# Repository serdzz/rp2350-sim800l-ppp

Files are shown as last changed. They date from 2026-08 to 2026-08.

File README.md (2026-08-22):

# RP2350-Plus + SIM800L → PPP → embassy-net

Embassy-приложение для Waveshare RP2350-Plus, которое поднимает интернет через
GSM-модуль SIM800L: настройка модема на `atat`, IP-канал на `embassy-net-ppp`,
сокеты на `embassy-net`.

```
┌──────────── командный режим ────────────┐   ┌──────── data-режим ────────┐
 BufferedUart ──► atat::Ingress ──► ResponseSlot / UrcChannel
      ▲                                          BufferedUart ──► embassy-net-ppp
      └── atat::Client ── AT+CGDCONT / ATD*99#                          │
                                                          embassy-net (TCP/UDP/DNS)
```

Один и тот же UART обслуживает обе фазы, но **никогда одновременно**. Пока идёт
AT-настройка, задача ingress живёт внутри `select` и снимается автоматически, как
только модем ответил `CONNECT`. После этого UART целиком уходит в
`embassy_net_ppp::Runner::run`. Когда PPP-сессия разваливается, приложение шлёт
`+++` / `ATH`, возвращается в командный режим и повторяет цикл.

## Документация

* [ARCHITECTURE.md](ARCHITECTURE.md) — как собрана прошивка: задачи, потоки
  данных, ключевые решения и расход ресурсов.
* [hardware/nri-g13-shifter/](hardware/nri-g13-shifter/) — схема переходника
  монетоприёмника на BSS138 (KiCad).
* [docs/cmux.md](docs/cmux.md) — мультиплексор 27.010: формат кадров, ловушки
  спецификации, раздача каналов и находки на живом железе.

## Файлы

| Файл | Что внутри |
|---|---|
| `src/main.rs` | Инициализация периферии, стек, главный цикл «AT → PPP → восстановление» |
| `src/config.rs` | **APN, логин/пароль, строка дозвона, таймауты** — правьте здесь |
| `src/modem.rs` | AT-команды, ответы и URC для `atat` |
| `src/sim800l.rs` | Питание модуля и последовательность инициализации до `CONNECT` |
| `src/cmux.rs` | Протокол 27.010: кадры, сессия, управляющий канал — см. [docs/cmux.md](docs/cmux.md) |
| `src/cmux_transport.rs` | Раздача каналов CMUX поверх одного UART |
| `src/mqtt.rs` | Телеметрия и приём SMS в MQTT, подписка на команды |
| `src/led.rs` | Режимы зелёного светодиода на GP25 |
| `src/display.rs` | Экран SSD1306 по I2C: часы, заряд, шкала сигнала, состояние связи |
| `src/fuel.rs` | Топливомер MAX17048 на той же шине I2C |
| `src/coin.rs` | Кредит, коды монет, разбор команд (без зависимостей, тесты на хосте) |
| `src/coin_io.rs` | Линии монетоприёмника NRI G-13: снятие кода монеты и блокировка |
| `src/clock.rs` | Время от сети и шкала сигнала (без зависимостей, тесты на хосте) |
| `src/health.rs` | Счётчики обрывов связи (без зависимостей, тесты на хосте) |
| `src/app.rs` | Демо-нагрузка поверх поднятого IP: DNS + HTTP GET |
| `src/battery.rs` | Замер VSYS/VBAT, определение источника питания |
| `src/lipo.rs` | Кривая заряда Li-Po (без зависимостей, тестируется на хосте) |
| `src/fmt.rs` | Фасад логирования: `info!`/`warn!`/`unwrap!` → defmt или log |
| `src/usb_logger.rs` | USB CDC-ACM логгер (только в сборке `log-usb`) |
| `src/io_compat.rs` | Мост `embedded-io-async` 0.7 ↔ 0.6 (см. «Версии крейтов») |
| `at-tests/` | Хостовые тесты формата AT-команд и дайджестера |

## Схема подключения

| SIM800L | RP2350-Plus | Примечание |
|---|---|---|
| `TXD` | `GP1` (UART0 RX) | |
| `RXD` | `GP0` (UART0 TX) | **нужен делитель 3.3 В → 2.8 В** |
| `PWRKEY` | `GP2` | опционально, если модуль не стартует сам |
| — | `GP16` / `GP17` | SDA / SCL: экран SSD1306 и топливомер MAX17048 (I2C0) |
| — | `GP3`…`GP8` | линии монетоприёмника, см. ниже |
| `GND` | `GND` | общая земля обязательна |
| `VCC` | **отдельный источник 3.4–4.4 В** | 2 А импульсами |

Два момента, на которых спотыкается большинство сборок:

1. **Питание.** SIM800L в момент передачи потребляет до 2 А. От пина `3V3` платы
   он не заработает — нужен отдельный источник (Li-Ion, LDO на 4 В) и
   конденсатор 1000 мкФ рядом с модулем. Симптом нехватки тока — URC
   `NORMAL POWER DOWN` в логе.
2. **Уровни.** Вход `RXD` модуля рассчитан на 2.8 В. Подавать на него 3.3 В
   напрямую — за пределами спецификации; поставьте делитель или преобразователь
   уровней. Выход `TXD` (2.8 В) RP2350 читает как логическую единицу без
   доработок.

Пины UART меняются в `src/main.rs` (`p.PIN_0` / `p.PIN_1`), но оставайтесь в
пределах одного `UART0` — иначе поправьте и `bind_interrupts!`.

## Топливомер MAX17048

SparkFun Qwiic Fuel Gauge вешается на ту же шину I2C, что и экран: `GP16` (SDA)
и `GP17` (SCL), адрес `0x36`. Аккумулятор подключается к самому топливомеру, а
не к плате — он меряет напряжение прямо на банке.

Заряд выводится на экран рядом с часами. Если топливомера нет, там стоит
прочерк: пустое место читалось бы как «показа заряда не предусмотрено».

### Зачем он, если есть замер VSYS

Затем, что `battery.rs` меряет не банку, а VSYS, и **при воткнутом USB о
батарее не говорит ничего** — VBUS через диод задаёт VSYS независимо от её
состояния. В логе это видно как «батарея не измеряется» в каждой строке.

У MAX17048 такого ограничения нет. И считает он заряд не по напряжению, а по
своей модели разряда: под нагрузкой напряжение проседает, и пересчёт
«вольты → проценты» врёт тем сильнее, чем больше ток. У модема этот ток
доходит до двух ампер.

### Про общую шину

Экран работает с шиной асинхронно, а крейт `max170xx` блокирующий. Свести их
удалось потому, что `embassy_rp::I2c` реализует оба трейта сразу: экран ходит
через асинхронную обёртку `I2cDevice`, а топливомер берёт мьютекс и обращается
к шине напрямую. Транзакция там короткая, пара байт, так что блокировка внутри
асинхронной задачи безобидна.

## Монетоприёмник NRI G-13

Вариант с шестью параллельными линиями (не последовательный интерфейс).

| Контакт разъёма | Сигнал | RP2350-Plus |
|---|---|---|
| 1 | `GND` | `GND` |
| 2 | `UB` +12 В | отдельный источник 10–16 В, ~20 мА |
| 7 | output line 1 | `GP3` |
| 8 | output line 2 | `GP4` |
| 9 | output line 3 | `GP5` |
| 10 | output line 4 | `GP6` |
| 3 | output line 5 | `GP7` |
| 4 | output line 6 | `GP8` |
| 6 | total blocking | `GP9` через ключ, см. ниже |

Нумерация контактов и линий не совпадает — сверяйтесь с таблицей, а не со
здравым смыслом.

Каждая линия **двунаправленная**: приёмник выдаёт по ней импульс 100 мс при
опознанной монете, и она же, удерживаемая в нуле, блокирует свой канал.
Поэтому в прошивке это `Flex`, а не обычный вход: открытый канал — вход с
подтяжкой, закрытый — выход, притянутый к земле. Высокий уровень на линию не
выдаётся никогда — с той стороны открытый коллектор.

### Согласование уровней: BSS138 на каждую линию

Линии приёмника живут в 12-вольтовом мире, плата — в 3,3-вольтовом, и по
каждой линии нужно и читать, и писать. Проверенное решение — **двунаправленный
преобразователь на BSS138**, по одному на линию:

```text
        +3.3 В (затвор)
             │
   GP3 ──────┤ BSS138 ├────── output line 1
   (вход с      (сток к приёмнику,
    подтяжкой)   исток к плате)
```

Внешние резисторы не нужны: со стороны платы работает встроенная подтяжка
RP2350 (её включает `Flex::set_pull(Pull::Up)`), со стороны приёмника — его
собственная. Так собран рабочий автомат на MSP430
(`bahilizator_svn/hardware/main_baord/coin.sch`, `Q10…Q15`), и там же прошивка
включает внутренние подтяжки контроллера.

Для справки, требования из схемы подключения (`G-13.6000-1 d`, стр. 22):

| | напряжение |
|---|---|
| блокировка канала | `≤ 1 В` |
| приём канала | `≥ 3,5 В` |
| допустимое на линии | до 35 В, до 150 мА |

Заводить линии на выводы напрямую **нельзя**: 3,3 В ниже порога приёма, и это
ещё до вопроса о том, что на линии может оказаться.

### Полная блокировка (контакт 6)

Закрывает приём целиком, независимо от поканальной маски. Активен **высоким**:
блокировка `≥ 3,5 В`, приём `≤ 1 В`, выдерживает до 35 В.

Схема та же, что у линий, плюс подтяжка стока к `+5 В` — так это сделано в
рабочем автомате (`Q5` и `R45` 10 кОм на той же схеме):

```text
                        +3.3 В        +5 В
                           │            │
                           │           10к
                           │            │
  GP9 ──10к── +3.3 В   ────┤ BSS138 ├───┴──── контакт 6 (total blocking)
```

Каскад **не инвертирует**: `GP9` высокий → полевик закрыт → 10к тянет линию к
5 В → блокировка. Поэтому в `src/config.rs`:

```rust
pub const COIN_TOTAL_BLOCK_INVERTED: bool = false;
```

Резистор 10 кОм от `GP9` к `+3.3 В` — не из схемы-образца, а добавка: без него
вывод в сбросе не управляется, линия уходит к нулю, и **мёртвый автомат
принимает монеты, не давая кредита**. С подтяжкой неуправляемый вывод означает
«заблокировано».

Если собрали инвертирующий каскад (например, NPN с подтяжкой к +12 В),
поставьте `COIN_TOTAL_BLOCK_INVERTED = true`.

### Монета опознаётся кодом на линиях

Прошивка снимает состояние всех шести линий разом и ищет получившийся код в
таблице. Это покрывает оба способа, которыми приёмник умеет сообщать монету:

* **одна монета на линию** — код однобитный (`0b010000` = линия 5);
* **двоичный код** — код многобитный (`0b000101` = пины 1 и 3 вместе).

Второе документация допускает прямо: «possible to transmit coin signals in a
binary code or assign more than one line to a type of coin».

Считать линии по отдельности нельзя: при двоичном коде одно евро зажигает два
пина, и шесть независимых счётчиков насчитали бы две монеты.

### Столбец на шильдике читается двояко — решает монета

Значения 1…6 в столбце — это либо номер линии, либо код. Глазами это не
различить, поэтому в `src/config.rs` перечислены **оба** варианта:

```rust
pub const COINS: &[coin::Coin] = &[
    coin::Coin { mask: 0b010000, value: 100, name: "EUR 1 (линия 5)" },
    coin::Coin { mask: 0b000101, value: 100, name: "EUR 1 (код 5)" },
    coin::Coin { mask: 0b100000, value: 100, name: "жетон (линия 6)" },
    coin::Coin { mask: 0b000110, value: 100, name: "жетон (код 6)" },
];
```

Столкнуться они не могут: при однобитной раскладке `0b000101` не появится
никогда (две линии разом не зажигаются), при двоичной не появится `0b010000`
(кода 16 на шильдике нет). Бросьте монету — лог скажет, какой вариант ваш:

```
COIN: EUR 1 (линия 5) (код 0b010000), номинал 100, кредит 100
```

Увидели — лишнюю строку из таблицы удалите. Неизвестный код печатается готовым
к вписыванию.

Для справки, что на шильдике экземпляра `06V01/5-14000084-008` (11/06):

| Столбец | Монета | Каналы |
|---|---|---|
| 1 | LVL 1,- | 01, 06 |
| 2 | RUR 5,- | 02, 07 |
| 3 | UAH 0,50 | 03, 08 |
| 4 | UAH 1,- | 04, 09 |
| 5 | **EUR 1,-** | 05, 10 |
| 6 | жетон | 12…16 |

Жетоны различить нельзя — все пять каналов дают один код.

### Ненужные монеты глушите переключателями, а не линиями

Латы, рубли и гривны прошивка не засчитает, но приёмник их всё равно
**проглотит** — они провалятся в кассу, а клиент останется без товара и без
денег. Закрывать их надо на самом приёмнике, по каналам:

* `S1.1…8` — каналы 1–8, `S2.1…8` — каналы 9–16;
* монета занимает **два канала** (обычная полоса приёма и узкая), выключать
  надо оба: лат — это `S1.1` и `S1.6`.

Команда `coin/block` глушит линии и остаётся полезной при однобитной раскладке.
При двоичном коде она почти бесполезна: пин 1 участвует и в лате, и в гривне, и
в евро, так что закрытие линии калечит чужие коды. Поэтому
`COIN_BLOCK_DEFAULT` равен нулю.

### Можно ли принимать евро кроме одного

Только 1 € запрограммирован заводом. Два блока настроек (`B-0` / `B-1`,
переключатель `S1.10`) у этого экземпляра содержат одинаковые наборы, так что
переключение ничего не даст.

Зато доступно обучение: `S2.9` = TEACH Mode, учить можно каналы 10 и 11, из
которых **11 свободен**. Порядок: `S2.9` в TEACH, `S2.3` (канал 11) включить,
бросить монету 10 раз до щелчка заслонки, оба переключателя выключить — второй
щелчок означает, что записалось. Два щелчка вместо одного — не записалось,
обычно из-за перекрытия с уже известной монетой; тогда повторить с `S2.10` в
положении `Teachband wide`.

Полный набор евро (10/20/50 центов, 2 €) требует программатора NRI с
программой KUNEMP.

### Переключатели на корпусе

| Группа | Позиции | Функция |
|---|---|---|
| S1 | 1…8 | заглушить каналы 1–8 |
| S1 | 9 | CASINO / NORMAL |
| S1 | 10 | Block 1 / Block 0 |
| S2 | 1…8 | заглушить каналы 9–16 |
| S2 | 9 | TEACH / NORMAL |
| S2 | 10 | Teachband wide / normal |

## Топики MQTT

| Топик | Направление | Тело |
|---|---|---|
| `rp2350-sim800l/csq` | публикуем, retain | `<rssi>` из `+CSQ`, раз в 60 с |
| `rp2350-sim800l/sms` | публикуем, retain | текст принятого SMS |
| `rp2350-sim800l/coin` | публикуем | `{"coin":"EUR 1","code":5,"value":100,"credit":100}` |
| `rp2350-sim800l/led` | подписаны | `ON`, `OFF`, `BLINK`, `TOGGLE` |
| `rp2350-sim800l/coin/block` | подписаны | `none`, `all`, `1,3` — какие линии заблокировать |
| `rp2350-sim800l/sms/send/<номер>` | подписаны | текст SMS в теле, номер в топике |
| `rp2350-sim800l/coin/total` | подписаны | `block` / `accept` — закрыть приём целиком |

Событие монеты идёт без `retain`: оно имеет смысл в момент наступления, а не
как последнее известное состояние. Команда блокировки, наоборот, задаёт
состояние целиком — присланная маска заменяет предыдущую, а не дополняет её.

Поканальная и полная блокировки независимы: закрытый автомат не отменяет того,
какие монеты в нём не принимаются, когда он открыт. Тело `block`/`accept`, а не
`on`/`off`, потому что «ON» одинаково правдоподобно читается и как «блокировка
включена», и как «приём включён». Пока приём закрыт, на экране рядом с кредитом
горит `ЗАКРЫТО` — иначе закрытый приёмник выглядит как сломанный.

### Отправка SMS

Номер — последний сегмент топика, текст — тело сообщения:

```bash
mosquitto_pub -h broker.hivemq.com \
  -t rp2350-sim800l/sms/send/37120000000 -m 'Coin jam on line 3'
```

**Номер только цифрами, без плюса.** В имени топика MQTT плюс запрещён — это
подстановочный знак, — и брокер такую публикацию отвергнет. Прошивка
подставляет его сама.

**Текст только ASCII, до 160 символов.** Кириллица требует `AT+CSCS="UCS2"` и
перекодировки всего сообщения вместе с номером; отправить её как есть — значит
получить абракадабру, поэтому прошивка честно отказывается и пишет причину в
лог.

Отправка идёт не из MQTT-задачи, а из той, что держит AT-канал: она занимает
секунды и требует модема, а MQTT-клиент за это время потерял бы соединение по
keepalive. Между командой и отправкой сообщение лежит в очереди на четыре
штуки.

```bash
# закрыть приём целиком
mosquitto_pub -h broker.hivemq.com -t rp2350-sim800l/coin/total -m 'block'

# заблокировать первую и третью линии
mosquitto_pub -h broker.hivemq.com -t rp2350-sim800l/coin/block -m '1,3'
# снять блокировку
mosquitto_pub -h broker.hivemq.com -t rp2350-sim800l/coin/block -m 'none'
```

## Настройка под оператора

Всё в `src/config.rs`:

```rust
pub const APN: &str = "internet";          // APN оператора
pub const PPP_USERNAME: &[u8] = b"";       // PAP-логин, обычно пустой
pub const PPP_PASSWORD: &[u8] = b"";
pub const DIAL_STRING: &str = "*99***1#";  // некоторые прошивки хотят "*99#"
```

## Логи: два бэкенда

Выбираются feature-флагом, включён должен быть ровно один. Макросы
`info!`/`warn!`/`error!`/`debug!`/`unwrap!` объявлены в `src/fmt.rs` и
разворачиваются либо в `defmt`, либо в `log` — код приложения от выбора не
зависит.

| | `log-rtt` (по умолчанию) | `log-usb` |
|---|---|---|
| Транспорт | RTT через отладчик | USB CDC-ACM (виртуальный COM-порт) |
| Нужен отладчик | да | **нет** |
| Чем читать | `probe-rs` / `cargo run` | любой serial-терминал |
| Паники | печатаются с бэктрейсом | не видны (см. ниже) |
| Flash | ~197 КиБ | ~201 КиБ |
| RAM (bss) | ~44 КиБ | ~45 КиБ |

### `log-usb`: лог по USB, без отладчика

```bash
cargo build-usb        # алиас в .cargo/config.toml

# BOOTSEL + USB, затем:
picotool load -u -v -x -t elf target/thumbv8m.main-none-eabihf/release/rp2350-sim800l

# Плата поднимется как виртуальный COM-порт:
screen /dev/tty.usbmodem*  115200      # macOS
picocom /dev/ttyACM0 -b 115200         # Linux
```

Скорость порта роли не играет — CDC-ACM её игнорирует. Формат строки:

```
[INFO ] 4.312 SIM800L: CPIN = READY
```

Если читаете порт скриптом, а не `screen`/`picocom`, переведите tty в raw —
иначе терминальная дисциплина портит многобайтные UTF-8 символы (кириллица
в логе поедет):

```bash
stty -f /dev/cu.usbmodem* raw -echo -istrip
```

Готовый вариант со всем этим внутри:

```bash
./tools/capture-log.py 120        # 120 секунд лога
```

Он же говорит, если порт занят: терминал держит устройство монопольно, и
запущенный `screen` со стороны выглядит как намертво замолчавшая плата.

Что стоит знать про этот режим:

* **Первые строки теряются.** Хост enumerate'ит порт около секунды; всё, что
  приложение успело написать раньше, оседает в буфере на 2 КиБ и вытесняется.
  Чтобы поймать самый старт — держите терминал открытым и передёрните плату
  кнопкой RUN.
* **Паники не видны.** `panic-probe` без `print-defmt` просто выполняет `udf`,
  а отправить сообщение через USB уже некому: executor остановлен. Отлаживать
  паники нужно в RTT-сборке.
* **`atat` молчит.** У версии 0.24 нет feature `log`, поэтому её внутренние
  сообщения в этом режиме пропадают. Логи самого приложения не страдают.
* VID/PID `0xc0de:0xcafe` — тестовая пара из примеров Embassy. Для серийного
  изделия нужна своя.

Порог логирования и размер буфера — константы `LEVEL` и `LOG_BUF_SIZE` в
`src/usb_logger.rs`.

### Диагностика подключения к сети

Лог при инициализации показывает не «получилось / не получилось», а причину:

```
SIM800L: IMSI 2470xxxxxxxxxxx — домашняя сеть MCC 247 / MNC 02
SIM800L: CSQ 20 (-73 дБм) | CREG 2 — ищет сеть | CGREG 2 — ищет сеть
SIM800L: регистрации нет; сканирую сети (AT+COPS=?, до 3 мин)…
SIM800L: видимые сети: +COPS: (2,"TELE2","TELE2","24702"),(1,"LMT GSM",...)
```

Как читать `<stat>` из `+CREG?` / `+CGREG?`:

| `stat` | Значение | Куда копать |
|---|---|---|
| 0 | не ищет | радиотракт выключен |
| 1 / 5 | зарегистрирован (дома / роуминг) | норма |
| 2 | ищет сеть | питание, антенна или сети нет в эфире |
| 3 | **отказано** | сеть видна, но не пускает: SIM, тариф или роуминг |

`AT+COPS=?` (за флагом `SCAN_OPERATORS_ON_FAILURE`) показывает все сети в
эфире; первое число в скобках — `2` текущая, `1` доступна, `3` запрещена.
`IMSI` даёт домашнюю сеть карты — сравнив её со списком, видно, отказывает
свой оператор или чужой в роуминге.

**Перезагрузки модуля отслеживаются отдельно.** `RDY` во время ожидания
регистрации прерывает цикл сразу, а не через две минуты опроса уже
перезагрузившейся железки. Три перезагрузки подряд — почти наверняка провал
питания: регистрация идёт на полной мощности передатчика, и просадка сбрасывает
модуль ровно в этот момент.

## Сборка и прошивка

```bash
rustup target add thumbv8m.main-none-eabihf

# С отладчиком (Picoprobe / Raspberry Pi Debug Probe) — сразу видно defmt-лог:
cargo run --release

# Без отладчика: зажать BOOTSEL, воткнуть USB, затем
cargo build --release
picotool load -u -v -x -t elf target/thumbv8m.main-none-eabihf/release/rp2350-sim800l
```

`probe-rs` для RP2350 указан в `.cargo/config.toml` как `--chip RP235x`.

`memory.x` задан под 4 МиБ flash (минимальная комплектация RP2350-Plus). Для
16-мегабайтной версии поднимите `LENGTH` у `FLASH` до `16384K`.

Размеры выше — для сборки со включённым `USE_CMUX` и MQTT. Обе ветки подъёма
компилируются в один образ, поэтому флаг стоит около 18 КиБ; подробности в
[ARCHITECTURE.md](ARCHITECTURE.md).

## Питание: батарея, VBAT и SIM800L

Разобрано по [официальной схеме RP2350-Plus](https://files.waveshare.com/wiki/RP2350-Plus/RP2350_Plus.pdf).

```text
  VBUS ──┤>├─ D1 ──┬── VSYS ──┬── R1 200K ─┬─ Q1 SI2306 ── GP29/ADC3
  VBAT ──┤>├─ D2 ──┘          │            ├─ R7 100K ── GND
   ▲  (P3, PH1.25)            │            └─ C7 100nF ── GND
   └── ETA6096 (заряд 1 А)    └── MP28164 (buck-boost) ── 3V3
```

### Измерение напряжения

Реализовано в `src/battery.rs`, задача логирует раз в минуту.

| Сигнал | Что это |
|---|---|
| `GP29` / `ADC3` | **VSYS / 3** — делитель R1 200K / R7 100K, как на Pico |
| `GP24` | сенсор VBUS: высокий = воткнут USB |
| `GP23` | `MODE/SYNC` у MP28164: высокий = постоянная ШИМ |

`Q1` (SI2306) стоит между делителем и GP29, затвор жёстко на 3V3. Управлять им
не нужно — пока плата запитана, он открыт; когда 3V3 снят, он отвязывает GP29
от VSYS, чтобы делитель не питал ногу МК и не сажал аккумулятор.

На время замера код поднимает `GP23`: в энергосберегающем режиме преобразователя
пульсации VSYS дают разброс в десятки милливольт.

Два ограничения, которые надо принять как данность:

* **При воткнутом USB напряжение батареи не измеряется.** VSYS задаёт VBUS через
  D1 (≈4.7 В) независимо от аккумулятора, а отдельной линии замера VBAT на плате
  нет.
* На батарее `VBAT = VSYS + Vf(D2)`. Падение на диоде зависит от тока, поэтому
  `SCHOTTKY_DROP_MV` в `src/battery.rs` — прикидка (250 мВ), которую стоит
  откалибровать вольтметром прямо на аккумуляторе.

### Куда подключать питание SIM800L

| Источник | Годится | Почему |
|---|---|---|
| `3V3` (пин 36) | **нет** | 3.3 В ниже минимума 3.4 В, а MP28164 не отдаст 2 А |
| `VSYS` (пин 39) | **нет** | при USB там ≈4.7 В — выше предела 4.4 В; на батарее импульсы 2 А идут через D2 и роняют VSYS так, что плата уходит в сброс |
| **VBAT** (разъём P3 или клеммы аккумулятора) | **да** | 3.4–4.2 В ровно в окне модуля, а импульсный ток берётся с самой банки |

VBAT на 40-пиновую гребёнку **не выведен** — доступ только через батарейный
разъём PH1.25-2P. Подключаться нужно параллельно ему: Y-переходник на PH1.25
либо пайка к клеммам аккумулятора.

```text
   [Li-Po] ──┬── PH1.25 ──► RP2350-Plus (P3)
             │
             └──────────────► SIM800L VCC
                              + 1000 мкФ low-ESR у самого модуля
   GND ── общая точка (звезда от минуса аккумулятора)
```

Что учесть:

* **Электролит 1000 мкФ low-ESR прямо на пины `VCC`/`GND` модуля — обязателен.**
  Не на рейку макетки, а на сам разъём. Проверено на этом стенде: без него
  модуль уходил в перезагрузку каждые ~11 секунд (14 сбросов за 172 с), с ним —
  ни одного за 140 с. Показательно, что умирал он ровно на первой передаче:
  `CSQ` успевал вырасти с 0 до 20, и через 6 мс приходил `Break error`.
  Приём модулю даётся на десятках миллиампер, а регистрация требует передачи
  на полной мощности — поэтому симптом выглядит как «сигнал есть, регистрации
  нет».
* **Провода к модулю — короткие и толстые.** Импульсы 2 А по 577 мкс с частотой
  216 Гц: лишние 100 мОм в проводе дают просадку 0.2 В.
* **Батарея должна отдавать 2 А.** Мелкая банка на 300–500 мА·ч просядет ниже
  3.4 В на первой же передаче, и модуль выдаст `NORMAL POWER DOWN`.
* **Заряд ограничен 1 А** (R13 = 160 кОм; 82 кОм → 2 А, 66 кОм → 2.5 А). Если
  SIM800L потребляет больше, чем даёт зарядник, аккумулятор разряжается даже при
  воткнутом USB.
* **Модуль будет запитан всегда**, пока подключена батарея — даже когда плата
  выключена через `3V3_EN`. Если это важно, ставьте ключ верхнего плеча
  (P-канальный MOSFET) на линию VCC модуля или уводите модуль в power-down
  через `PWRKEY`.
* Уровни UART не меняются: `TXD` модуля 2.8 В плата читает как единицу, а на
  `GP0 → RXD` по-прежнему нужен делитель.

## Сторожевой таймер

Устройство работает без присмотра, поэтому в прошивке включён watchdog RP2350:
порог 8 секунд, кормление раз в 2 секунды из отдельной задачи.

Кормление не безусловное. Задача, кормящая по таймеру, доказывает только то,
что исполнитель крутится, — а зависнуть можно и с живым исполнителем:

| Что сломалось | Что замечает |
|---|---|
| паника, холостой цикл, зависший исполнитель | кормить некому |
| обмен с модемом встал при живых задачах | 10 минут молчания модема |

Порог молчания щедрый намеренно: в рабочем режиме модем отвечает не реже чем
раз в 30 секунд (опрос CSQ), но `AT+COPS=?` сканирует сети молча и занимает
минуты. Перезагрузка посреди сканирования была бы хуже болезни.

### PWRKEY и тёплый перезапуск

Импульс PWRKEY **переключает** питание SIM800L, а не включает его. После
перезагрузки по сторожевому таймеру модуль остался работать, и импульс бы его
выключил — поэтому на тёплом перезапуске он пропускается.

Тёплый перезапуск отличается от холодного старта по скретч-регистру watchdog:
он переживает перезагрузку чипа, но обнуляется при потере питания.

Если предположение окажется неверным и модуль всё-таки выключен, три неудачных
подъёма подряд (около полуминуты) заставят прошивку дёрнуть PWRKEY.

В логе перезагрузка видна строкой `WDT: прошлый запуск оборвала перезагрузка`.

## Тесты

```bash
./run-at-tests.sh
```

Гоняет на хосте ровно тот `src/modem.rs`, что уходит в прошивку, и проверяет
байты на проводе, разбор ответов и поведение дайджестера. Два случая, которые
эти тесты закрывают, и на которых легко обжечься:

* `ATD*99***1#` должна уйти **без кавычек** — по умолчанию `atat` заключает
  строковые аргументы в кавычки, и модем на `ATD"*99***1#"` отвечает `ERROR`.
  Отсюда `quote_escape_strings = false` у `DialPpp`.
* В перечислении `Urc` не должно быть префиксов, которые приходят ответом на
  наши же команды (`+CREG`, `+CSQ`, `+CPIN`, `+CGATT`). Дайджестер `atat`
  проверяет URC-теги **до** разбора ответа, так что такой тег увёл бы ответ в
  URC-канал, а `send()` завис бы до таймаута.

## Версии крейтов

В графе зависимостей намеренно уживаются по две версии трёх крейтов — это
следствие того, что `atat` 0.24 отстаёт от текущего Embassy:

| Крейт | `atat` | Embassy | Как разрешено |
|---|---|---|---|
| `embedded-io-async` | 0.6 | 0.7 | обёртка `Compat` в `src/io_compat.rs` |
| `heapless` | 0.8 | 0.9 | типы AT-команд используют `atat::heapless` |
| `embassy-time` | 0.4 | 0.5 | обе версии ходят в один `embassy-time-driver` 0.2, драйвер даёт `embassy-rp` — работает корректно |

Когда `atat` обновится, `src/io_compat.rs` удаляется, а `Compat(x)` в
`src/main.rs` заменяется на `x`.

## Что дальше

Полезная логика пишется в `src/app.rs` — `Stack<'static>` даёт обычные
TCP/UDP/DNS сокеты `embassy-net`. Для HTTP удобно добавить `reqwless`, для
MQTT — `rust-mqtt`; оба работают поверх `embassy-net` без изменений в этом коде.

Что стоит доделать под конкретную задачу:

* **Аппаратный flow control.** Без RTS/CTS единственная защита от переполнения —
  2 КиБ RX-буфера UART. Если модуль разведён с `RTS`/`CTS`, переключитесь на
  `BufferedUart::new_with_rtscts` и добавьте `AT+IFC=2,2` в `bring_up`.
* **Watchdog.** `embassy_rp::watchdog` на случай, если модем зависнет в
  состоянии, из которого `+++`/`ATH` не вытаскивает.
* **Экономия энергии.** `AT+CFUN=0` между сеансами и `AT+CSCLK=2` для сна модуля.

## Лицензия

Двойная, на выбор: [MIT](LICENSE-MIT) или [Apache-2.0](LICENSE-APACHE) — как
принято в экосистеме Rust и в самом Embassy.

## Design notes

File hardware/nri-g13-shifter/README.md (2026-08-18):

# Переходник NRI G-13 ↔ RP2350-Plus

Плата согласования уровней между монетоприёмником NRI G-13 (12 В) и платой
RP2350-Plus (3.3 В). Шесть линий монет и линия полной блокировки.

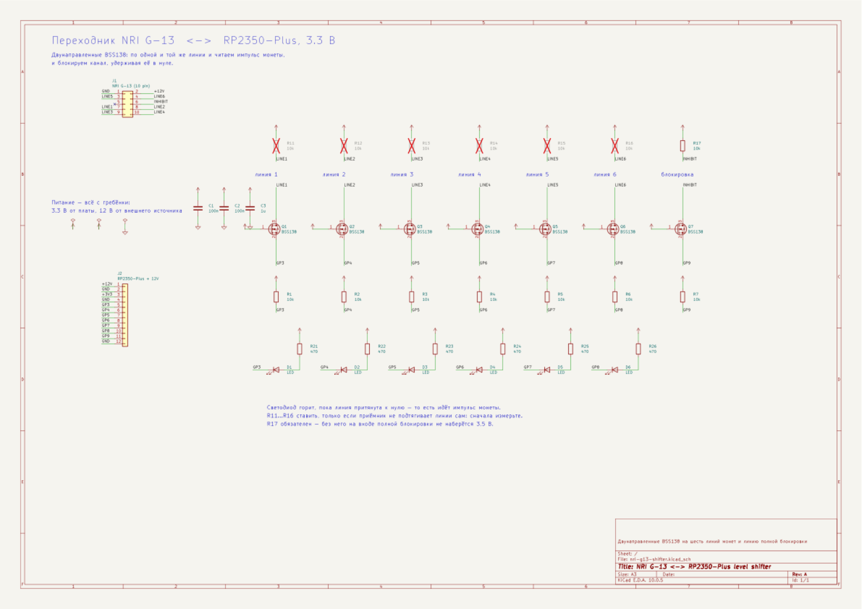
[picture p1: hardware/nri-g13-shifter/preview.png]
схема


Открывать: `nri-g13-shifter.kicad_pro`. Для просмотра без KiCad —
[nri-g13-shifter.pdf](nri-g13-shifter.pdf).

## Зачем она нужна

Линии приёмника **двунаправленные**: по одной и той же линии приходит импульс
об опознанной монете и задаётся блокировка канала — удержанием линии в нуле.
Напрямую с выводом RP2350 их соединять нельзя:

| | из даташита `G-13.6000-1 d`, стр. 22 |
|---|---|
| блокировка канала | `≤ 1 В` |
| приём канала | `≥ 3,5 В` |
| допустимо на линии | до 35 В, до 150 мА |

Порог приёма **3,5 В выше, чем выдаёт плата**. Отсюда двунаправленный
преобразователь на BSS138 — по одному на линию: затвор на 3.3 В, исток к
плате, сток к приёмнику. Ровно так сделано в предыдущем поколении устройства
(`bahilizator_svn/hardware/main_baord/coin.sch`, `Q10…Q15`).

## Разъёмы

**J1** — к приёмнику, 10 контактов. Нумерация контактов и линий **не
совпадает**, это не опечатка:

| Контакт | Сигнал | Цепь |
|---|---|---|
| 1 | GND | `GND` |
| 2 | UB +12 В | `+12V` |
| 3 | output line 5 | `LINE5` |
| 4 | output line 6 | `LINE6` |
| 5 | return | не подключён |
| 6 | total blocking | `INHIBIT` |
| 7 | output line 1 | `LINE1` |
| 8 | output line 2 | `LINE2` |
| 9 | output line 3 | `LINE3` |
| 10 | output line 4 | `LINE4` |

Контакт 5 не подключаем: он нужен только варианту Casino, где по нему идёт
сигнал датчика приёма.

**J2** — единственный разъём к остальному устройству, 12 контактов. Питание
приёмника идёт через него же: отдельный клеммник означал бы второй кабель к
устройству, которое и так стоит в тесном корпусе.

| Контакт | Цепь | Куда |
|---|---|---|
| 1 | `+12V` | внешний источник 10–16 В, ~20 мА |
| 2 | `GND` | общая земля |
| 3 | `+3V3` | с платы RP2350-Plus |
| 4 | `GND` | |
| 5…11 | `GP3`…`GP9` | линии 1…6 и блокировка |
| 12 | `GND` | |

12 В на плату RP2350-Plus, разумеется, не подаётся — этот контакт идёт мимо
неё, прямо к источнику.

## Что и зачем стоит

| Позиции | Что | Зачем |
|---|---|---|
| Q1…Q7 | BSS138 | двунаправленное согласование 3.3 В ↔ 12 В |
| R1…R7 | 10 кОм к 3.3 В | подтяжка со стороны платы |
| R17 | 10 кОм к 12 В | **обязателен**: без него на входе блокировки не наберётся 3,5 В |
| R11…R16 | 10 кОм к 12 В | по месту, см. ниже |
| D1…D6 + R21…R26 | светодиод и 1 кОм | индикация импульса монеты |
| C1…C3 | 100n, 100n, 10µ | развязка по питанию |

### R11…R16 ставить не спешите

Линии монет — открытый коллектор, и подтягивать их должен кто-то один.
Приёмник обычно делает это сам. Измерьте линию относительно земли на
запитанном приёмнике, ничего к ней не подключая:

* **есть напряжение** — приёмник тянет сам, эти резисторы не нужны;
* **ноль или болтается** — поставьте.

Поэтому в схеме они помечены как неустанавливаемые (в KiCad — крестом).

### R7 держит автомат закрытым, пока контроллер в сбросе

`R7` подтягивает `GP9` к 3.3 В. Каскад не инвертирует: высокий уровень на
`GP9` → полевик закрыт → `R17` тянет линию к 12 В → **блокировка**.

Пока контроллер в сбросе, вывод не управляется, и без этого резистора линия
ушла бы к нулю — мёртвый автомат принимал бы монеты, не давая кредита. С ним
неуправляемое состояние совпадает с безопасным.

В прошивке этому соответствует `COIN_TOTAL_BLOCK_INVERTED = false`.

### Светодиода на GP9 нет намеренно

Он с резистором перетянул бы подтяжку `R7` и сломал бы ровно то свойство, ради
которого она стоит.

## Индикаторы отвечают на открытый вопрос

Светодиод горит, пока линия притянута к нулю, то есть весь импульс монеты
(100 мс). Этого хватает, чтобы **без прошивки** понять, как приёмник сообщает
о монете:

* мигнул **один** светодиод — одна монета на линию;
* мигнули **два** — двоичный код.

Это тот самый вопрос, который сейчас не решён: в `config::COINS` лежат оба
варианта, и первая же брошенная монета покажет, какой из них ваш.

## Плата

| верх | низ |
|---|---|
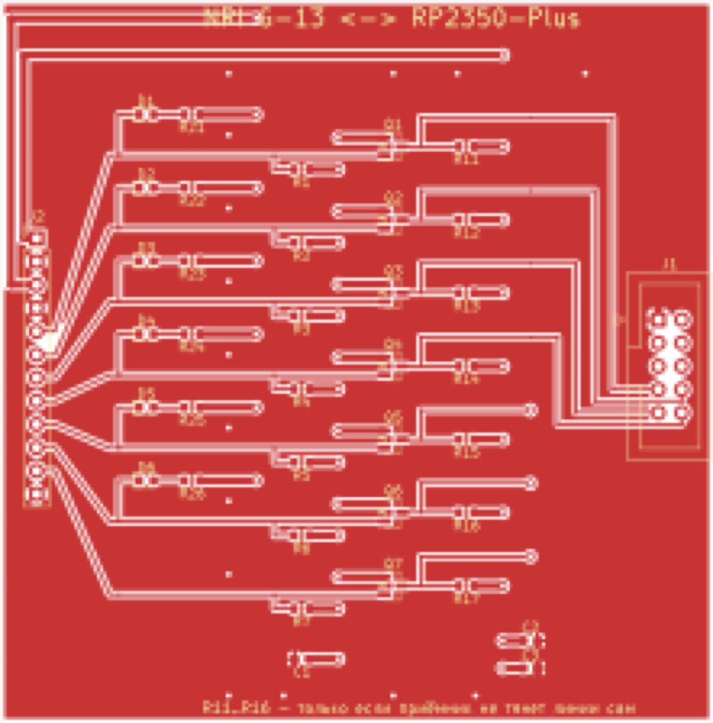
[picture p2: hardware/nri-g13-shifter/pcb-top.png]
верх
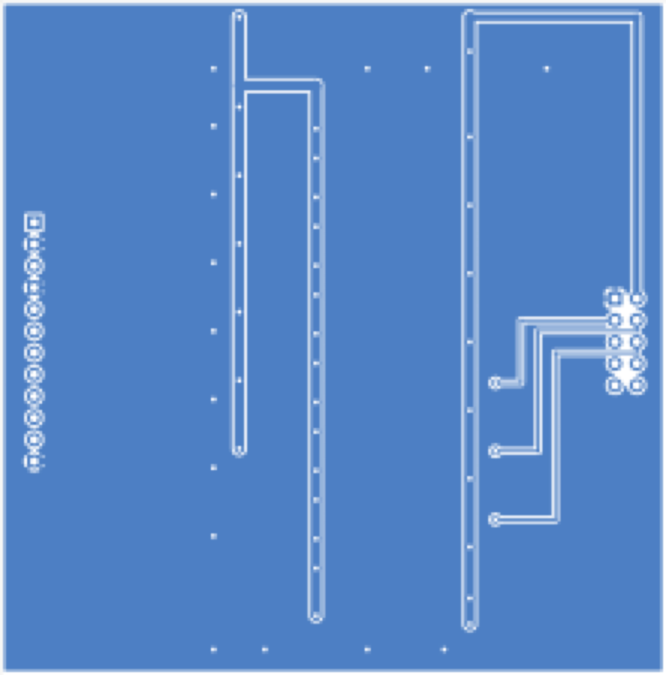
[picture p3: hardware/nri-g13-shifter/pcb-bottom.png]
низ
|  |  |

Два слоя, **78 × 79 мм**, земля залита с обеих сторон.

| | ширина |
|---|---|
| магистральные шины 3.3 В и 12 В | 1.2 мм |
| отводы питания | 0.8 мм |
| сигналы | 0.3 мм |

Ток тут копеечный — приёмник берёт около 20 мА, — так что ширина питания взята
не по нагреву, а ради надёжности: такую дорожку труднее подорвать при монтаже и
переделках.

Строка канала сжата до 8 мм за счёт того, что полосы внутри неё не
перекрываются по горизонтали: индикатор и отвод к разъёму делят одну высоту,
просто живут на разных участках платы.

Разводка ортогональная, и это не украшательство, а то, что позволило её
сгенерировать:

* **верх** — сигналы, горизонтальными строками, по строке на канал;
* **низ** — питание, вертикальными шинами, пересекающими все строки.

Пересечься они не могут по построению, а семь строк отличаются только
координатой `y`.

Две тонкости, которые пришлось развести руками:

* **Отвод к разъёму обходит R11…R17 сверху.** В линию его не поставить — там
  уже сидит сток полевика, и дорожка к разъёму упёрлась бы в резистор.
* **Разбор разъёма приёмника идёт по двум слоям.** Порядок контактов там свой
  и в строки ложится с перехлёстом; половина линий уходит вниз, и внутри
  каждой половины порядок уже монотонный, то есть пересечений нет.

Разбор гребёнки платы, наоборот, однослойный: её выводы и строки идут в одном
порядке, и веер получается непересекающимся сам собой.

### Про заливку

Земля залита по обоим слоям, и обе заливки получились сплошными: сигналы
живут наверху горизонтальными полосами, питание внизу вертикальными, и ни то,
ни другое не режет плату поперёк.

Дорожки земли под заливкой оставлены намеренно. Заливка на плотной плате может
разорваться на куски, и надеяться, что все они окажутся связаны, нельзя, —
а дорожка связывает гарантированно.

Сшивающие отверстия стоят **строго на этих дорожках**, а не в чистом поле:
отверстие, висящее в заливке, связью не считается ни для проверки, ни на
плате, если медь вокруг него окажется отрезанной. Это, кстати, единственная
ошибка, которую KiCad поймал в заливке: тринадцать отверстий по нижнему краю
оказались висящими, и их пришлось переставить.

## На производство

```bash
./make_gerbers.sh
```

Кладёт в `gerber/` полный комплект и собирает `nri-g13-shifter-gerber.zip` —
его и загружать на завод.

| Параметр | Значение |
|---|---|
| Слоёв | 2 |
| Размер | 78 × 79 мм |
| Толщина | 1.6 мм |
| Минимальная дорожка | 0.3 мм |
| Минимальный зазор | 0.2 мм |
| Отверстия | 0.6 мм (переходные, 50 шт) и 1.0 мм (разъёмы, 22 шт) |
| Поясок переходного | 0.2 мм |

Ничего дефицитного тут нет: дешёвые заводы держат 0.127 мм по дорожке и
0.2 мм по отверстию, то есть запас двукратный и больше.

Отчёт по сверловке — заодно проверка замысла: 50 отверстий по 0.6 мм это ровно
переходные, 22 по 1.0 мм — контакты двух разъёмов. Несовпадение здесь означало
бы, что на плате есть что-то, чего в разводке не задумывалось.

**`--check-zones` в скрипте обязателен.** Заливку заполняет KiCad, а не
`gen_pcb.py`, и без этого флага на завод уехала бы плата с пустыми зонами —
то есть без земли.

## Монтаж на заводе

`make_gerbers.sh` кладёт в `assembly/` то, без чего на монтаж не примут:

| Файл | Что это |
|---|---|
| `bom.csv` | перечень элементов с артикулами склада |
| `cpl.csv` | координаты и поворот каждого элемента |

`--exclude-dnp` стоит в обоих вызовах: `R11…R16` ставить не нужно, и завод не
должен узнавать об этом из примечания в письме.

### Порядок заказа на JLCPCB

1. **Плата.** На главной «Order now», загрузить `nri-g13-shifter-gerber.zip`.
   Размер и число слоёв подхватятся сами: 78 × 79 мм, два слоя. Из настроек
   менять нечего — толщина 1.6 мм и покрытие HASL идут по умолчанию.
   Минимальный тираж плат — 5 штук.

2. **Включить монтаж.** Переключатель `PCB Assembly`. Сторона — только
   верхняя, все элементы там. Количество собираемых плат можно взять меньше,
   чем плат: собрать две, а три оставить про запас, выйдет заметно дешевле.

3. **Загрузить файлы.** `assembly/bom.csv` в поле BOM, `assembly/cpl.csv` в
   поле CPL. Разъёмы в них исключены намеренно — см. ниже.

   Оба файла уже приведены к тому виду, который завод принимает: обозначения
   перечислены поштучно, а не диапазонами вида `D1-D6`, и шапка координат
   названа так, как ждёт JLCPCB — `Designator, Mid X, Mid Y, Rotation, Layer`.
   KiCad по умолчанию делает и то, и другое по-своему, а завод на этом
   спотыкается молча: `File processing failed` без единой подробности.

4. **Сверить детали.** Шесть строк должны опознаться по артикулам без ручного
   подбора. Проверить наличие на складе: артикулы верные, но остатки живут
   своей жизнью.

5. **Сверить установку — не пропускать этот шаг.** Показывают плату с
   расставленными деталями. Смотреть надо на светодиоды и BSS138: соглашение о
   нуле поворота у KiCad и у завода совпадает не всегда. Для светодиода
   ошибка означает обратную полярность, то есть шесть неработающих
   индикаторов.

6. Корзина, доставка, оплата.

Разъёмы `J1` и `J2` придётся припаять самому: выводной монтаж у JLCPCB —
отдельная услуга, а двадцать два вывода паяются руками за десять минут.
Купить их проще локально, чем ждать в той же посылке.

Из чего складывается цена: сами платы, разовая настройка станка, разовая плата
за расширенную позицию (`BSS138`), стоимость деталей и доставка. Точные суммы
показывает корзина — на глаз это десятки долларов, а не сотни, но верить надо
корзине, а не мне.

### Артикулы JLCPCB

Проставлены в схеме, при компонентах, и оттуда попадают и в `bom.csv`, и в
плату. Все сверены по каталогу, а не восстановлены по памяти: неверный код —
это не опечатка, а другая деталь на плате.

| Позиция | Артикул | Что это | Набор |
|---|---|---|---|
| R1…R7, R17 | `C25804` | 10 кОм 0603 1% | базовый |
| R21…R26 | `C23179` | 470 Ом 0603 1% | базовый |
| C1, C2 | `C14663` | 100 нФ 50 В 0603 X7R | базовый |
| C3 | `C15849` | 1 мкФ 50 В 0603 | базовый |
| D1…D6 | `C2286` | светодиод красный 0603 | базовый |
| Q1…Q7 | `C78284` | BSS138 SOT-23, порог 0.8 В | расширенный |

За расширенную позицию берут разовую плату за настройку станка. Менять BSS138
на базовый 2N7002 (`C8545`) не стоит: у того порог отпирания вдвое выше, а весь
смысл каскада в том, чтобы он открывался от 3.3 В.

**Светодиод именно красный.** Зелёный в корпусе 0603 имеет прямое напряжение
3.3 В — ровно столько, сколько на шине, — и от неё попросту не зажёгся бы.
У красного 1.8…2.4 В, и через 470 Ом получается около 3 мА: для вспышки длиной
100 мс этого хватает уверенно.

Артикулы стоит перепроверить на наличие в момент заказа — склад живёт своей
жизнью.

### Два номинала исправлены при подборе артикулов

Оба раза ошибка была не в схеме, а в том, чего в схеме не написано.

**`C3`: было 10 мкФ, стало 1 мкФ.** В корпусе 0603 десять микрофарад бывают
только на 10 вольт, а `C3` сидит на шине 12 В — номинал был просто
неработоспособен. В схеме написано «10u», рабочего напряжения там нет, а в
каталоге есть.

**`R21…R26`: было 1 кОм, стало 470 Ом.** Заодно сменился цвет светодиода, и по
той же причине: у зелёного прямое напряжение равно напряжению шины.

### Две вещи, которые придётся сделать руками

**Повороты.** Соглашение о нуле поворота у KiCad и у заводов совпадает не
всегда — чаще всего расходятся как раз светодиоды и SOT-23. В просмотрщике
заказа видно, куда смотрит первый вывод; сверьтесь по нему, прежде чем платить.
Для светодиода это ещё и полярность.

**Разъёмы.** `J1` и `J2` — выводной монтаж, у большинства заводов это отдельная
услуга, дороже поверхностного. Двадцать два вывода паяются руками за десять
минут, так что дешевле исключить их из заказа и поставить самому.

## Как пересобрать

Схема генерируется скриптом: семь каналов отличаются только именами цепей, и
копировать их мышью — верный способ ошибиться в одном из семи.

```bash
python3 gen_sch.py                                    # схема + bom.md
kicad-cli sch erc nri-g13-shifter.kicad_sch
kicad-cli sch export netlist --format kicadsexpr -o net.txt nri-g13-shifter.kicad_sch
python3 gen_pcb.py                                    # плата
kicad-cli pcb drc --refill-zones --save-board --schematic-parity nri-g13-shifter.kicad_pcb
```

`gen_pcb.py` берёт цепи, номиналы и посадочные места **из нетлиста схемы**, а
не задаёт их заново: разойтись со схемой они не могут в принципе.

`--refill-zones --save-board` обязателен: скрипт описывает контур заливки, а
заполняет её KiCad. Без этого шага плата откроется с пустыми зонами.

Определения символов скрипт берёт из установленных библиотек KiCad и встраивает
в файл целиком: распиновка BSS138 и разъёмов настоящая, а схема при этом
открывается на машине без этих библиотек.

## Состояние

Проверено средствами KiCad 10:

| Проверка | Результат |
|---|---|
| ERC схемы | 0 нарушений |
| DRC платы | 0 нарушений |
| Неразведённые связи | 0 |
| Сверка платы со схемой | 0 расхождений |

Нетлист вдобавок сверен с замыслом по каждому контакту вручную.

**Плата не изготавливалась и не собиралась.** Всё сказанное — про файлы,
а не про железо.

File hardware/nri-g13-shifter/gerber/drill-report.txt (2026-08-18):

Drill report for nri-g13-shifter.kicad_pcb
Created on 2026-08-19T00:22:11

Copper Layer Stackup:
    =============================================================
    L1 :  F.Cu                      front
    L2 :  B.Cu                      back

Drill file 'nri-g13-shifter-PTH.drl' contains
    plated through holes:
    =============================================================
    T1  0.600mm  0.0236"  (50 holes))
    T2  1.000mm  0.0394"  (22 holes))

    Total plated holes count 72

Drill file 'nri-g13-shifter-NPTH.drl' contains
    unplated through holes:
    =============================================================

    Total unplated holes count 0

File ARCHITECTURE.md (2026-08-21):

# Устройство прошивки

Как собрана прошивка RP2350-Plus + SIM800L: какие задачи крутятся, кто чем
владеет и почему сделано именно так. Пошаговые инструкции — в [README](README.md),
подробности мультиплексора — в [docs/cmux.md](docs/cmux.md).

## Задача, которую решает конструкция

У SIM800L **один** UART. Через него нужно и настраивать модем AT-командами, и
гонять IP-трафик. Эти два режима несовместимы: после `ATD*99***1#` модем
уходит в data-режим и AT-команд не понимает.

Отсюда два пути, оба живут в прошивке:

| | без мультиплексора | с мультиплексором |
|---|---|---|
| Владелец UART | попеременно `atat` или PPP | всегда насос CMUX |
| Модем во время PPP | **недоступен** | доступен |
| Опрос `CSQ`, приём SMS при поднятом канале | невозможны | работают |
| Проверено на железе | многократно | да |
| Переключатель | `config::USE_CMUX` | |

Второй путь и есть причина, по которой в проекте появился 27.010: без него
телеметрия и SMS требовали бы разрыва связи.

## Что крутится одновременно

Задачи embassy, все на одном исполнителе:

```
main ──┬─ run_plain            UART → atat, потом UART → PPP (по очереди)
       └─ run_multiplexed      UART → насос CMUX, дальше всё параллельно
             ├─ pump           разбор кадров, раздача по каналам
             ├─ atat::Ingress  AT-канал (DLCI 1)
             ├─ ppp_runner     PPP-канал (DLCI 2)
             └─ at_fut         опрос CSQ + приём SMS

net_task        стек embassy-net
mqtt_task       брокер: публикации и подписка
led_task        режимы светодиода
display_task    перерисовка экрана раз в секунду
coin_task       снятие кода монеты с шести линий
total_block_task линия полной блокировки приёмника
watchdog_task   кормит сторожевой таймер, пока прошивка выглядит живой
battery_task    замер VSYS раз в минуту
urc_task        логирование URC модема
demo_task       HTTP-запрос раз в 30 с
logger_task     USB CDC (только в сборке log-usb)
```

## Поток данных в режиме мультиплексора

```
                    ┌──────────────┐  UIH(DLCI 1)   ┌──────────────┐
  UART RX ─► pump ──┤ cmux::Decoder├───────────────►│ Pipe → atat  │
                    │ cmux::Session│  UIH(DLCI 2)   ├──────────────┤
                    └──────────────┘───────────────►│ Pipe → PPP   │
                            │  DLCI 0                └──────────────┘
                            └─► управляющие сообщения (MSC, CLD, FCon)

  UART TX ◄── Mutex ◄── Channel::write (обрамляет в UIH)
                     ◄── send_frame     (SABM, UA, DM, DISC)
```

Наверх поднимается обычный `embassy-net`: PPP отдаёт IP-адрес и DNS от
оператора, дальше работают привычные TCP/UDP-сокеты.

## Модули

| Файл | Строк | Назначение |
|---|---|---|
| `cmux.rs` | 1581 | Протокол 27.010: кадры, сессия, управляющий канал. **Без зависимостей** |
| `main.rs` | 774 | Инициализация периферии, два пути подъёма, приём SMS |
| `cmux_transport.rs` | 519 | Обвязка мультиплексора под embassy: насос, каналы, мьютекс |
| `sim800l.rs` | 505 | Последовательность подъёма модема, диагностика регистрации |
| `modem.rs` | 441 | AT-команды и URC для `atat`. **Без зависимостей от embassy** |
| `mqtt.rs` | 328 | Публикация телеметрии, SMS и монет, подписка на команды |
| `clock.rs` | 288 | Время от сети и шкала сигнала. **Без зависимостей** |
| `display.rs` | 202 | Экран SSD1306: часы, кредит, состояние связи |
| `coin_io.rs` | 318 | Линии монетоприёмника: приём импульсов, блокировка каналов и полная |
| `battery.rs` | 141 | Замер VSYS, определение источника питания |
| `coin.rs` | 229 | Кредит и разбор команд блокировки. **Без зависимостей** |
| `fmt.rs` | 125 | Фасад логирования: defmt или log по feature-флагу |
| `usb_logger.rs` | 112 | USB CDC-ACM как транспорт лога |
| `config.rs` | 207 | Всё, что правится под оператора и стенд |
| `app.rs` | 90 | Демо-нагрузка: DNS + HTTP |
| `led.rs` | 84 | Режимы светодиода, включая мигание |
| `lipo.rs` | 84 | Кривая заряда Li-Po. **Без зависимостей** |
| `io_compat.rs` | 100 | Мост `embedded-io-async` 0.7 ↔ 0.6 |
| `watchdog.rs` | 102 | Сторожевой таймер и признак жизни модема |

## Ключевые решения

### Протокол отделён от ввода-вывода

`cmux.rs`, `modem.rs`, `lipo.rs`, `clock.rs`, `coin.rs` и `health.rs` не зависят ни от
embassy, ни от HAL. За счёт этого они подключаются в `at-tests/` через `#[path]`
и проверяются на хосте — **62 теста**, включая байты AT-команд на проводе и
кадры 27.010, сверенные с эталонами из спецификации.

Всё, что требует железа, вынесено в `cmux_transport.rs`, `sim800l.rs` и
`coin_io.rs` и проверяется только на стенде.

### Кадр UIH отправляется тремя записями

`Channel::write` не собирает кадр в буфере: заголовок, полезная нагрузка и
хвост уходят в UART по отдельности. Возможно это ровно потому, что у UIH
контрольная сумма не покрывает данные и считается заранее. Иначе на каждый
канал понадобился бы буфер в полтора килобайта только под передачу.

Плата за это — **мьютекс на все три записи**: если между ними вклинится другой
канал, погибнут оба кадра.

### Монета опознаётся кодом на линиях

Приёмник умеет сообщать монету двумя способами: одна монета на линию либо
двоичный код сразу по нескольким выводам. Который из них настроен на конкретном
экземпляре, по потёртому шильдику не понять.

Поэтому распознавание идёт по коду целиком: состояние всех шести линий
снимается разом, с выдержкой на разбег фронтов, и результат ищется в таблице.
Однобитный код — частный случай, так что гадать не нужно, а неизвестный код
печатается в лог готовым к вписыванию.

Задача при этом одна, а не шесть: при двоичном коде одно евро зажигает два
пина, и шесть независимых счётчиков насчитали бы две монеты.

Опрос раз в 5 мс вместо ожидания фронта — сознательно: ждать пришлось бы на
шести выводах одновременно, а потом всё равно выдерживать паузу. При импульсе
в 100 мс опрос проще и надёжнее.

Выдержка 60 мс и предел импульса 250 мс взяты не из расчёта, а из рабочего
автомата на MSP430 (`bahilizator_kwt_svn`), где они отработали в поле.

### Из залипшей линии кредит не печатается

Если линии не отпущены дольше предела, прошивка сообщает об этом и **продолжает
ждать**, а не возвращается к приёму. Выход по таймауту означал бы начисление
кредита за каждый проход цикла: пока линия залипла, отличить новую монету от
той же самой невозможно.

Именно так ошибается образец на MSP430 — там таймаут возвращает автомат в
IDLE, откуда он немедленно опознаёт ту же самую залипшую линию как следующую
монету. Лучше стоять и кричать в лог, чем печатать деньги.

### Линии монетоприёмника двунаправленные

По одной и той же линии приходит импульс о монете и задаётся блокировка канала:
удержание нуля означает «эту монету не принимать». Отсюда `Flex` вместо
`Input` — открытая линия живёт как вход с подтяжкой, закрытая как выход в ноль.
Единицу не выдаём никогда: с той стороны открытый коллектор, и в момент
импульса он потянул бы линию к земле против нашего выхода.

Заблокированные линии исключаются из снимаемого кода — иначе наша собственная
блокировка читалась бы как сработавший пин.

### Неуправляемый вывод обязан означать «заблокировано»

Линии приёмника 12-вольтовые, плата 3.3-вольтовая, и по каждой линии нужно и
читать, и писать. Поэтому между ними двунаправленный преобразователь на BSS138,
по одному на линию — так же, как в схеме предыдущего поколения устройства.

Вход полной блокировки активен высоким, а его порог `≥ 3.5 В` плата не выдаёт,
так что там тот же BSS138 плюс подтяжка к 5 В. Каскад не инвертирует.

Отдельно от согласования уровней стоит требование безопасности: пока
контроллер в сбросе, `GP9` не управляется, и линия ушла бы к нулю — мёртвый
автомат принимал бы монеты, не давая кредита. Лечится резистором 10 кОм от
`GP9` к 3.3 В: неуправляемое состояние становится «заблокировано».

Полярность знает один файл — `coin_io.rs` сам создаёт `Output`, вместо того
чтобы принимать готовый из `main`.

### Сторожевой таймер кормится не безусловно

Задача, кормящая по таймеру, доказывает лишь то, что исполнитель крутится.
За одно утро мы поймали два зависания разной природы: холостой цикл на ошибке
UART (исполнитель голодает) и запертую очередь URC (исполнитель жив, обмен с
модемом стоит). Вторую такая проверка не заметила бы — задачи живы, экран
перерисовывается.

Поэтому кормление привязано ещё и к признаку жизни модема: если от него не
пришло ни байта за 10 минут, кормить перестаём. Порог щедрый намеренно —
`AT+COPS=?` сканирует сети молча и занимает минуты.

Отсюда же следует неочевидное требование к PWRKEY: его импульс **переключает**
питание модуля, поэтому на тёплом перезапуске его нельзя повторять — иначе
сторожевой таймер сам бы выключал модем. Тёплый перезапуск отличается по
скретч-регистру watchdog, который переживает перезагрузку, но не потерю
питания.

### Счётчик отказов честнее мгновенного состояния

На экране рядом с `MQTT +` стоят два числа: обрывы сессии с брокером и обрывы
самого канала. Разница между «связь есть» и «связь есть прямо сейчас, а до
этого пропадала двадцать раз» видна только по ним — мгновенное состояние её
скрывает полностью.

Уровни считаются порознь, потому что и ломаются порознь: канал может стоять
при живом MQTT, а сессия — падать при исправном канале. Именно так и было,
когда сокет обрывал сам себя в тишине между публикациями.

Счётчик насыщается, а не переполняется: обнулившийся счётчик показал бы «всё
хорошо» — ровно противоположное правде. Выше 99 на экране пишется `>99`:
обрезка по ширине превратила бы «100» в «10», то есть опять солгала бы.

### Обратный напор естественный

Насос пишет разобранные данные в трубу канала. Если потребитель не читает,
насос встаёт на записи, перестаёт разбирать линию, UART упирается в
аппаратный буфер, и модем притормаживает. Отдельного механизма не понадобилось.

### Логирование через фасад

Макросы `info!`/`warn!` объявлены в `fmt.rs` и разворачиваются либо в `defmt`
(RTT, нужен отладчик), либо в `log` (USB CDC, отладчик не нужен). Код
приложения от выбора не зависит.

Собственные типы получают `#[derive(Debug)]` всегда и `defmt::Format` — через
`#[cfg_attr(feature = "_defmt", ...)]`, потому что `{:?}` у `log` требует
`Debug`, а у `defmt` — свой трейт.

### Три версии крейтов в одном дереве

`atat` 0.24 отстаёт от текущего embassy, отсюда:

| Крейт | `atat` | embassy | Как разрешено |
|---|---|---|---|
| `embedded-io-async` | 0.6 | 0.7 | обёртка `Compat` в `io_compat.rs` |
| `heapless` | 0.8 | 0.9 | AT-типы используют `atat::heapless` |
| `embassy-time` | 0.4 | 0.5 | обе ходят в один `embassy-time-driver` 0.2 |

Последнее работает потому, что драйвер времени один — его даёт `embassy-rp`.

## Расход ресурсов

Сборка `log-usb` со включённым `USE_CMUX`:

```
   text     data      bss
 205732     2100    44744
```

То есть около 200 КиБ flash из 4 МиБ и 44 КиБ RAM из 520 КиБ. Крупнейшие
статьи: MQTT-клиент (~61 КиБ), обе ветки подъёма в одном образе (~18 КиБ),
трубы каналов CMUX (2 КиБ + 512 Б в bss).

`USE_CMUX` — константа, а не cargo feature, поэтому компилируются обе ветки, и
future главной задачи размерен по большей из них. Переводится в feature, если
место понадобится.

## Проверка

```bash
./run-at-tests.sh                                    # 62 теста на хосте
cargo build --release                                # defmt по RTT
cargo build-usb                                      # текст по USB CDC
cargo clippy --release
./tools/capture-log.py 120                           # лог с платы
```

Хостовые тесты гоняют **ровно те файлы**, что уходят в прошивку, — через
`#[path]`, а не копии.

## Что осталось за кадром

- **Управление потоком CMUX.** `FCon`/`FCoff` разбираются и пишутся в лог, но
  не исполняются: остановка передачи по всем каналам, кроме нулевого, — это
  работа в `Channel::write`, а живого `FCoff` от модема мы пока не видели.
- **Кириллица в SMS.** SIM800L в текстовом режиме отдаёт её UCS2-дампом;
  декодера нет.
- **Паники в сборке `log-usb`** не видны: `panic-probe` без `print-defmt`
  выполняет `udf`, а отправить сообщение по USB уже некому. Отлаживать паники
  нужно в RTT-сборке.
- **Аппаратный flow control UART** не задействован; защита от переполнения —
  только 2 КиБ приёмного буфера.

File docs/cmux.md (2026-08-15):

# Мультиплексор 3GPP TS 27.010

Разбор того, как в проекте сделан CMUX: формат кадров, ловушки спецификации,
раздача каналов и что выяснилось на живом железе.

Общее устройство прошивки — в [ARCHITECTURE.md](../ARCHITECTURE.md).

## Зачем

У SIM800L один UART, и после `ATD*99***1#` он уходит в data-режим, где
AT-команд не понимает. Пока поднят PPP, модем недоступен: нельзя ни спросить
уровень сигнала, ни принять SMS, ни узнать о деактивации PDP-контекста. Чтобы
задать один вопрос, приходилось рвать связь.

TS 27.010 поднимает поверх одного порта несколько логических каналов. PPP живёт
на одном, AT-команды — на другом, одновременно.

Измеренный результат на стенде: от `AT+CMUX` до полученного IP-адреса —
**0.7 секунды**, все три канала открываются с первой попытки.

```
[INFO ] 22.180 SIM800L: переходим в мультиплексный режим, N1 = 127
[INFO ] 22.219 CMUX: канал 0 открыт (попытка 1)
[INFO ] 22.240 CMUX: канал 1 открыт (попытка 1)
[INFO ] 22.260 CMUX: канал 2 открыт (попытка 1)
[INFO ] 22.269 SIM800L: CONNECT в канале — переходим в PPP
[INFO ] 22.887 PPP: адрес 10.17.170.155, пир Some(192.168.254.254)
[INFO ] 52.276 CMUX: CSQ 19 при поднятом PPP        ← ради этого всё
```

## Формат кадра, basic option

```
┌──────┬─────────┬─────────┬───────────┬─────────────┬─────┬──────┐
│ Flag │ Address │ Control │  Length   │ Information │ FCS │ Flag │
│ 0xF9 │  1 окт  │  1 окт  │ 1 или 2   │   0..N окт  │  1  │ 0xF9 │
└──────┴─────────┴─────────┴───────────┴─────────────┴─────┴──────┘
```

Байт-стаффинг не нужен: длина передаётся явно, поэтому `0xF9` внутри данных
разбор не ломает. Отдельный тест это проверяет.

**Адрес** (§5.2.1.2): `DLCI << 2 | C/R << 1 | EA`, где EA всегда 1.
DLCI 0 — управляющий канал.

**Управление** (таблица 2), бит P/F — это `0x10`:

| Кадр | Код | Смысл |
|---|---|---|
| SABM | `0x2F` | открыть канал |
| UA | `0x63` | подтверждение SABM или DISC |
| DM | `0x0F` | канал закрыт / отказ |
| DISC | `0x43` | закрыть канал |
| UIH | `0xEF` | данные, FCS только по заголовку |
| UI | `0x03` | данные, FCS по всему кадру |

**Длина** (§5.2.1.5): один октет `len << 1 | 1` до 127 байт; при большей длине
EA первого октета сбрасывается и следом идёт второй, всего 15 бит.

## Две ловушки спецификации

Обе способны дать кадры, которые молча отбраковываются другой стороной.
Поэтому в проекте они закреплены тестами против значений из документа.

### Порядок бит

По §5.2.2 поля передаются младшим битом вперёд, и все значения в
спецификации записаны в обратном к привычному порядке. Приложение же видит
обычные октеты.

Annex B.2 прямо советует не переворачивать биты руками, а взять **отражённую**
таблицу CRC. Так и сделано: таблица строится `const`-выражением, полином
`x⁸ + x² + x + 1` в отражённом виде `0xE0`.

Тест сверяет её с первыми 32 значениями и последним из Annex B, плюс два
независимых якоря:

- канонический кадр открытия управляющего канала — `F9 03 3F 01 1C F9`;
- приёмная константа §5.2.1.6 — прогон защищённых полей вместе с принятым
  FCS даёт `0xCF`.

### FCS у UIH не покрывает данные

§5.2.1.6: у UIH контрольная сумма считается **только по адресу, управлению и
длине**. Поле данных не защищено вовсе. У остальных типов FCS покрывает всё.

Перепутать эти два случая — значит получить кадры, которые не проходят проверку
на приёме. Тест портит байт полезной нагрузки и убеждается, что UIH это
переживает, а UI отбраковывается.

У этой особенности есть приятное следствие: контрольную сумму можно посчитать
**до** того, как данные уйдут в линию. На этом построена отправка без буфера —
см. ниже.

## Управляющий канал

Сообщения на DLCI 0 идут в формате «тип — длина — значение» (§5.4.6.1).
В октете типа: бит 1 — EA, бит 2 — C/R, биты 3–8 — сам тип.

| Сообщение | Октет типа (команда) | Назначение |
|---|---|---|
| MSC | `0xE3` | виртуальные сигналы V.24 |
| CLD | `0xC3` | закрыть мультиплексор |
| FCon | `0xA3` | приём возобновлён |
| FCoff | `0x63` | приём остановлен |
| NSC | `0x13` | команда не поддержана |

Октет сигналов V.24 (рисунок 10, таблица 7): `EA │ FC │ RTC │ RTR │ — │ — │ IC │ DV`.
У передающего DTE бит IC всегда 0, DV всегда 1, что даёт привычное `0x8D`.

**Отвечаем, не полагаясь на эту таблицу.** По §5.4.6.2 ответ несёт те же биты
типа, что и команда, поэтому даже незнакомую команду можно корректно отбить, а
на непонятую послать NSC с октетом её типа. Это важно: в PDF описания FCon,
FCoff и NSC обрываются переносом страницы, и видны не все биты.

Спецификация допускает многооктетные тип и длину, но ни один определённый в ней
тип их не использует — поддержан только однооктетный вариант, и `decode`
честно возвращает `None` при `EA = 0`.

## Раздача каналов

### Что определило конструкцию

`embassy_net_ppp::Runner::run` требует `BufRead + Write`. В embassy-sync
`BufRead` реализован **только у `Reader`**, получаемого из `Pipe::split()` — не
у самого `Pipe`.

Отсюда схема: труба на канал делится на читающую половину для потребителя и
пишущую для насоса. Половины стёрты по типу через `DynamicReader`/`DynamicWriter`,
иначе размер трубы протёк бы дженериком во все структуры.

`atat` хочет чтение и запись **разными объектами**, поэтому канал умеет
делиться: `Channel::split()` → `(ChannelRx, ChannelTx)`.

### Отправка без буфера на всю нагрузку

`UihFraming` готовит заголовок и хвост отдельно, кадр уходит тремя записями:

```rust
let framing = UihFraming::new(dlci, n)?;
let mut tx = self.tx.lock().await;      // мьютекс на все три записи
tx.write_all(framing.header()).await?;
tx.write_all(&buf[..n]).await?;
tx.write_all(framing.trailer()).await?;
```

Возможно это ровно из-за особенности FCS у UIH. Иначе на каждый канал
понадобился бы буфер в полтора килобайта только под передачу.

Мьютекс держится на все три записи: если между ними вклинится другой канал,
погибнут оба кадра. Тест сверяет потоковую сборку с обычной байт в байт для
длин по обе стороны границы 127.

### Насос

Читает UART, гоняет байты через `Decoder`, отдаёт событие в `Session` и
разводит результат:

- `Event::Data` на DLCI 0 → разбор управляющего сообщения и ответ;
- `Event::Data` на прочих → в трубу соответствующего канала;
- `RemoteOpen` / `RemoteDisconnect` → ответ UA или DM;
- ошибка разбора → в лог, декодер сам пересинхронизируется на следующем флаге.

Ошибки чтения UART не фатальны: насос переживает и мусор в линии, и
перезагрузку модема.

## Порядок подъёма

```
1. Обычный AT по сырому UART: связь, SIM, регистрация, PDP-контекст, attach
2. AT+CMUX=0,0,5,127          ← после этого AT-обмен по UART заканчивается
3. Запустить насос
4. SABM на DLCI 0, ждать UA   ← управляющий канал первым
5. SABM на DLCI 1 и 2, MSC на каждый
6. ATD*99***1# в канал 2, ждать CONNECT
7. Отдать канал 2 в PPP, канал 1 — в atat
```

Шаг 1 обязан быть **до** шага 2: всё, что проще сделать простыми AT-командами,
должно быть сделано заранее.

Дозвон на шаге 6 идёт сырыми байтами через `dial_on_stream`: он пишет `ATD` и
ждёт в потоке подстроку `CONNECT`. Второй экземпляр `atat` со своим
`ResponseSlot` ради одной команды не нужен.

Подтверждения `UA` приходят в насосе, а ждёт их другая задача, поэтому ожидание
сделано опросом общего `Session` под мьютексом раз в 20 мс. Подъём случается
один раз, и отдельный примитив синхронизации на каждый канал не окупается.

## Что выяснилось на железе

### Настройки задаются на конкретном канале

Самая дорогая находка. `AT+CMGF` и `AT+CNMI` отправлялись до `AT+CMUX`, и SMS
не приходили вовсе. После входа в мультиплексный режим **каждый DLCI — отдельный
виртуальный AT-интерфейс со своими настройками**, а прежний «канал» перестаёт
существовать. Извещение `+CMTI` было некому слать.

Настройка перенесена на тот канал, где потом ждут URC. Если добавляете команды,
меняющие поведение канала, — задавайте их там же.

### `AT+CIPSHUT` отвечает `SHUT OK`

Не `OK`. Дайджестер `atat` такой ответ не признаёт, строка остаётся в приёмном
буфере и приклеивается к ответу на следующую команду. На стенде это выглядело
как падение дозвона с `Error::Parse` через 5 мс после отправки, плюс дыра в
65 секунд — таймаут `AT+CIPSHUT`.

Лечится своим парсером успеха через `with_custom_success`.

### Ретраи `SABM` не понадобились

Заложены на случай, если модем пропустит первый кадр, пока переключает разбор
входного потока. На практике все три канала открывались с первой попытки во
всех запусках. Оставлены на всякий случай.

## Чего нет

- **Управление потоком.** `FCon`/`FCoff` разбираются и пишутся в лог, но не
  исполняются. Живого `FCoff` от SIM800L мы не видели.
- **Advanced option** (§5.2.7) с байт-стаффингом — только basic.
- **Многооктетные тип и длина** в сообщениях управляющего канала.
- **Подписка на несколько топиков одним пакетом** — ограничение `rust-mqtt`, к
  CMUX отношения не имеет, но встречается в том же коде.
- **Восстановление после `CLD` от модема**: команда разбирается и подтверждается,
  но сеанс не переподнимается автоматически.

## Ссылки

- [3GPP TS 27.010](https://www.arib.or.jp/english/html/overview/doc/STD-T63V12_30/5_Appendix/Rel11/27/27010-b00.pdf) — сам стандарт; §5.2 формат кадра, §5.4.6 управляющий канал, Annex B расчёт CRC
- 3GPP TS 27.007 — команда `AT+CMUX` и кодировка скорости порта

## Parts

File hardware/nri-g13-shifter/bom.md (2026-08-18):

# Спецификация

| Позиция | Номинал | Корпус | Ставить |
|---|---|---|---|
| C1 | 100n | C_0603_1608Metric | да |
| C2 | 100n | C_0603_1608Metric | да |
| C3 | 1u | C_0603_1608Metric | да |
| D1 | LED | LED_0603_1608Metric | да |
| D2 | LED | LED_0603_1608Metric | да |
| D3 | LED | LED_0603_1608Metric | да |
| D4 | LED | LED_0603_1608Metric | да |
| D5 | LED | LED_0603_1608Metric | да |
| D6 | LED | LED_0603_1608Metric | да |
| J1 | NRI G-13 (10 pin) | IDC-Header_2x05_P2.54mm_Vertical | да |
| J2 | RP2350-Plus + 12V | PinHeader_1x12_P2.54mm_Vertical | да |
| Q1 | BSS138 | SOT-23 | да |
| Q2 | BSS138 | SOT-23 | да |
| Q3 | BSS138 | SOT-23 | да |
| Q4 | BSS138 | SOT-23 | да |
| Q5 | BSS138 | SOT-23 | да |
| Q6 | BSS138 | SOT-23 | да |
| Q7 | BSS138 | SOT-23 | да |
| R1 | 10k | R_0603_1608Metric | да |
| R2 | 10k | R_0603_1608Metric | да |
| R3 | 10k | R_0603_1608Metric | да |
| R4 | 10k | R_0603_1608Metric | да |
| R5 | 10k | R_0603_1608Metric | да |
| R6 | 10k | R_0603_1608Metric | да |
| R7 | 10k | R_0603_1608Metric | да |
| R11 | 10k | R_0603_1608Metric | нет (по месту) |
| R12 | 10k | R_0603_1608Metric | нет (по месту) |
| R13 | 10k | R_0603_1608Metric | нет (по месту) |
| R14 | 10k | R_0603_1608Metric | нет (по месту) |
| R15 | 10k | R_0603_1608Metric | нет (по месту) |
| R16 | 10k | R_0603_1608Metric | нет (по месту) |
| R17 | 10k | R_0603_1608Metric | да |
| R21 | 470 | R_0603_1608Metric | да |
| R22 | 470 | R_0603_1608Metric | да |
| R23 | 470 | R_0603_1608Metric | да |
| R24 | 470 | R_0603_1608Metric | да |
| R25 | 470 | R_0603_1608Metric | да |
| R26 | 470 | R_0603_1608Metric | да |

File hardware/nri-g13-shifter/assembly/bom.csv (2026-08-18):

Comment | Designator | Footprint | LCSC Part # | Qty
100n | C1,C2 | Capacitor_SMD:C_0603_1608Metric | C14663 | 2
1u | C3 | Capacitor_SMD:C_0603_1608Metric | C15849 | 1
LED | D1,D2,D3,D4,D5,D6 | LED_SMD:LED_0603_1608Metric | C2286 | 6
BSS138 | Q1,Q2,Q3,Q4,Q5,Q6,Q7 | Package_TO_SOT_SMD:SOT-23 | C78284 | 7
10k | R1,R2,R3,R4,R5,R6,R7,R17 | Resistor_SMD:R_0603_1608Metric | C25804 | 8
470 | R21,R22,R23,R24,R25,R26 | Resistor_SMD:R_0603_1608Metric | C23179 | 6

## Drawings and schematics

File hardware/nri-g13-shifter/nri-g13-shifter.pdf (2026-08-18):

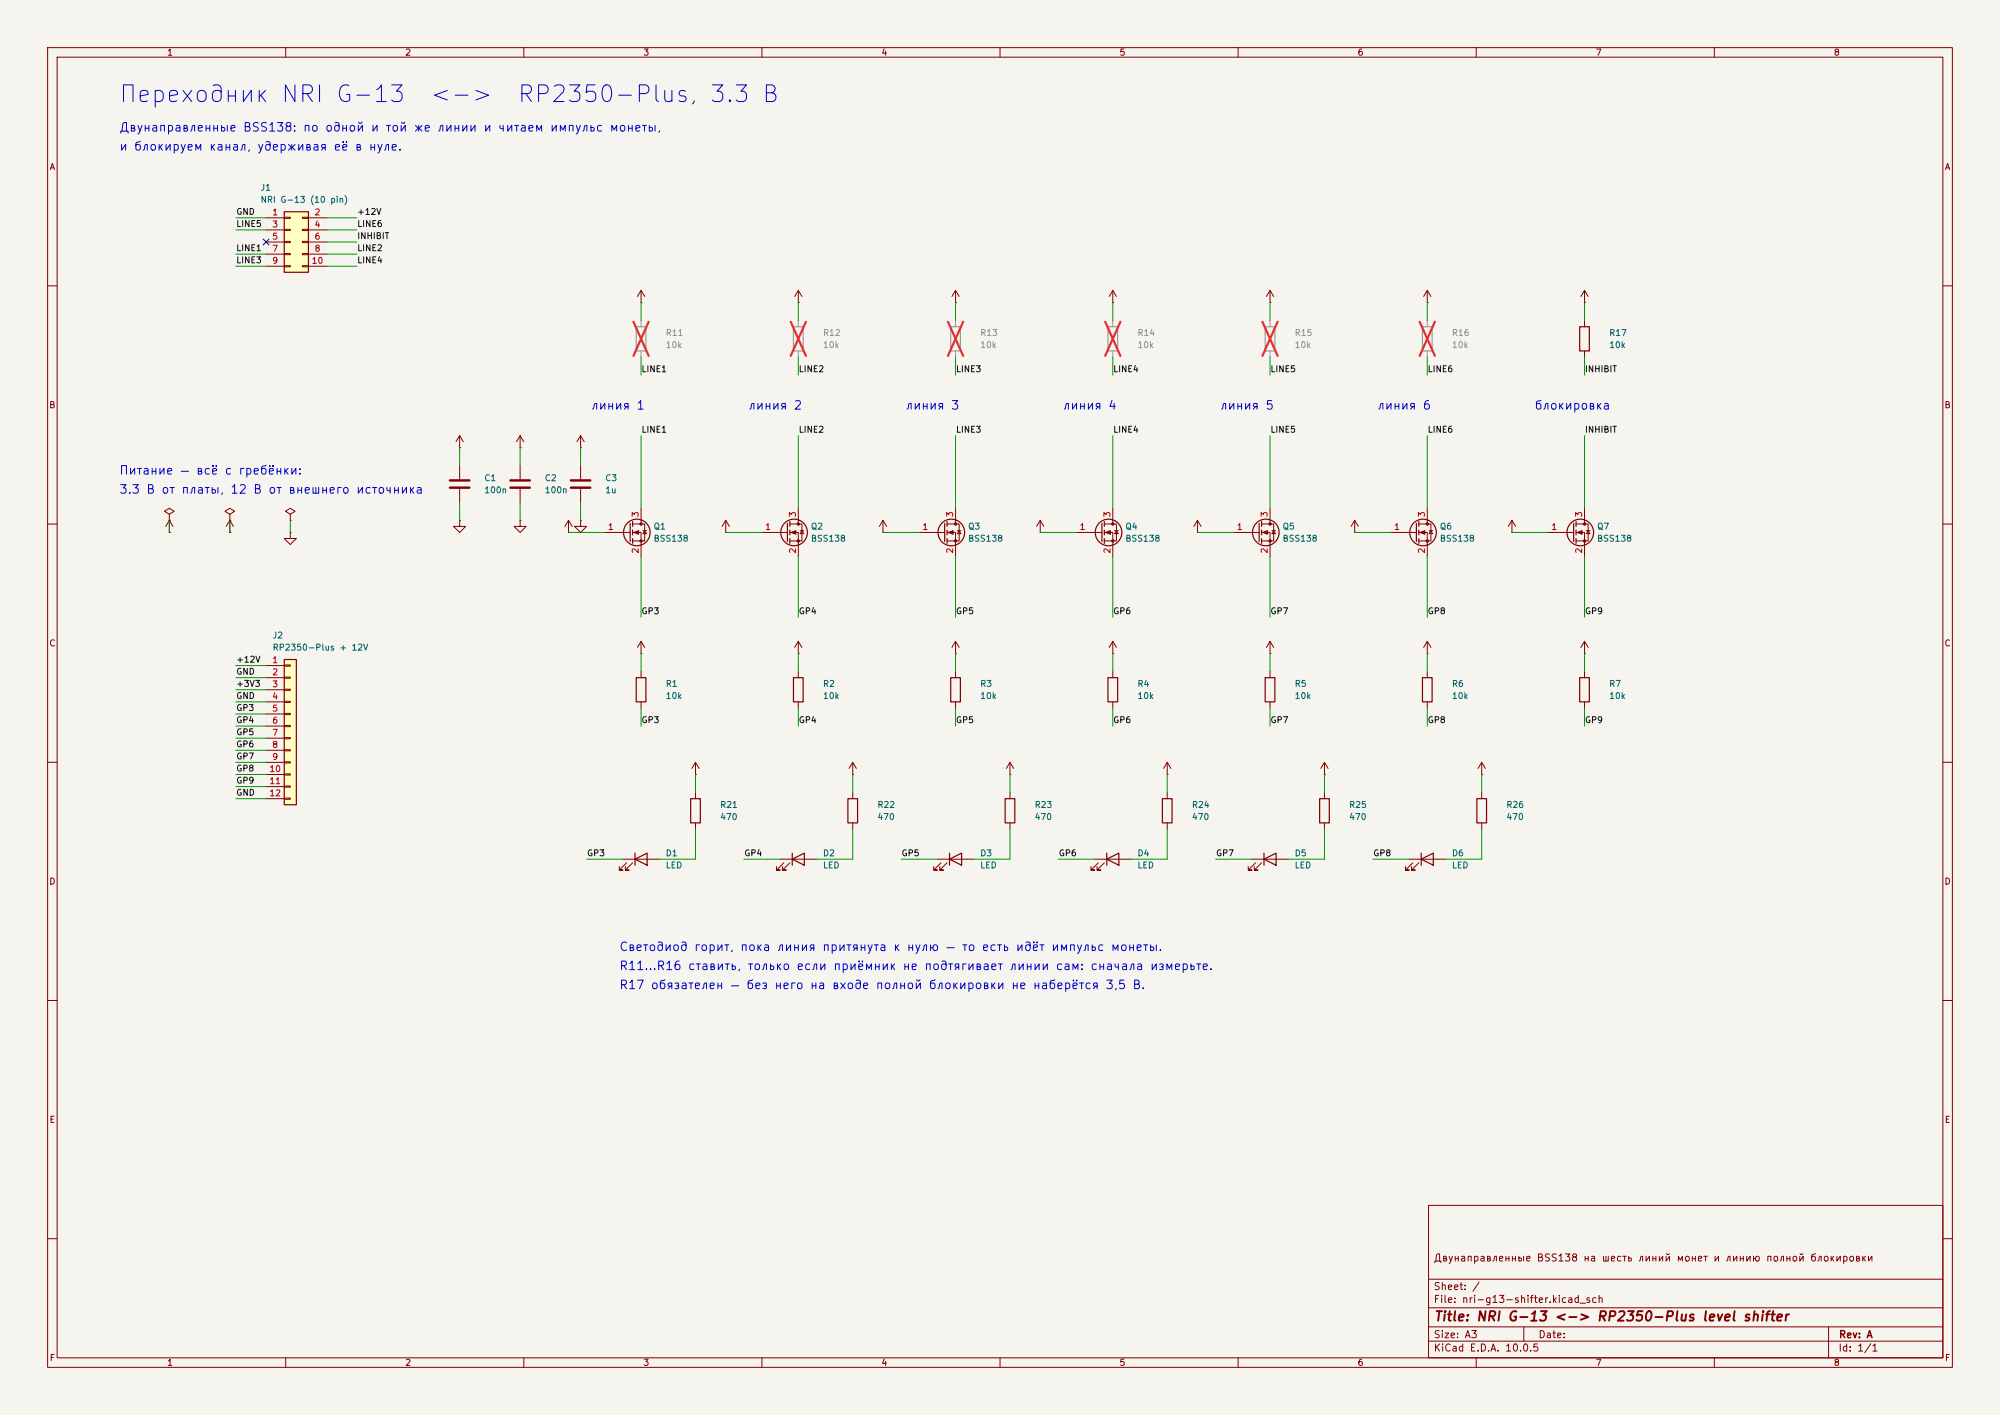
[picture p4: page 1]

Двунаправленные BSS138: по одной и той же линии и читаем импульс монеты,

Питание — всё с гребёнки:
3.3 В от платы, 12 В от внешнего источника

Светодиод горит, пока линия притянута к нулю — то есть идёт импульс монеты.
R11…R16 ставить, только если приёмник не подтягивает линии сам: сначала измерьте.
R17 обязателен — без него на входе полной блокировки не наберётся 3,5 В.

Двунаправленные BSS138 на шесть линий монет и линию полной блокировки

Sheet: /
File: nri-g13-shifter.kicad_sch
Title: NRI G-13 <-> RP2350-Plus level shifter

Size: A3 | Rev: A | F Date:
KiCad E.D.A. 10.0.5 | Id: 1/1

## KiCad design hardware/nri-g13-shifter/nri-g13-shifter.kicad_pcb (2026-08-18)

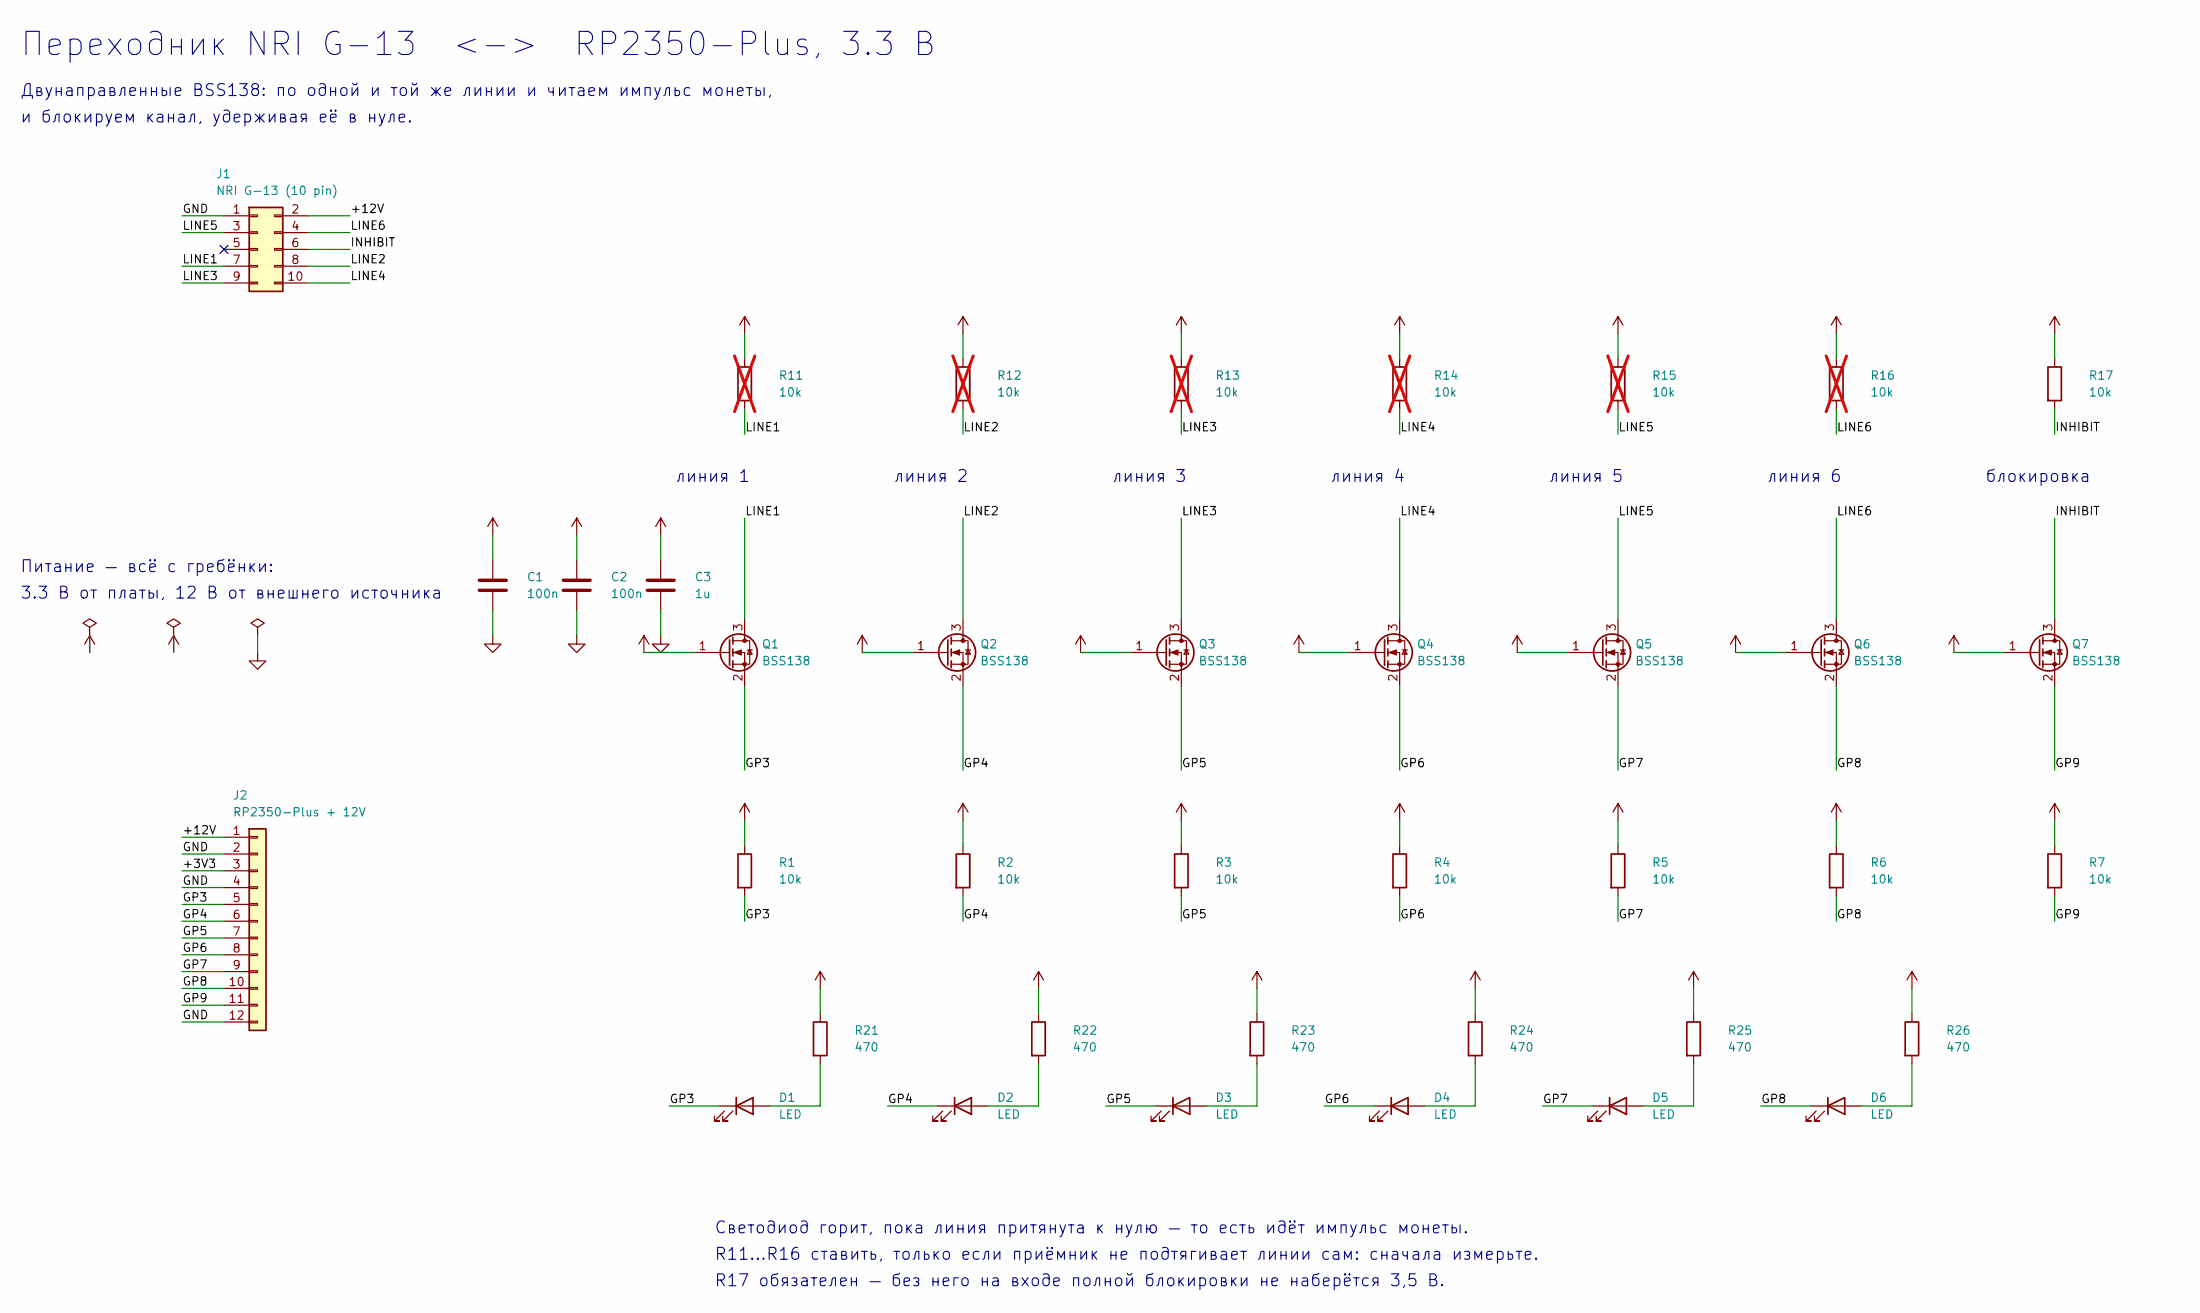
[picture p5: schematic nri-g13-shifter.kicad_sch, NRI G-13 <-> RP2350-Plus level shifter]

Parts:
C1, C2: 100n; C_0603_1608Metric; LCSC C14663
C3: 1u; C_0603_1608Metric; LCSC C15849
D1, D2, D3, D4, D5, D6: LED; LED_0603_1608Metric; LCSC C2286
J1: NRI G-13 (10 pin); IDC-Header_2x05_P2.54mm_Vertical
J2: RP2350-Plus + 12V; PinHeader_1x12_P2.54mm_Vertical
Q1, Q2, Q3, Q4, Q5, Q6, Q7: BSS138; SOT-23; LCSC C78284
R1, R2, R3, R4, R5, R6, R7, R17: 10k; R_0603_1608Metric; LCSC C25804
R11, R12, R13, R14, R15, R16: 10k; R_0603_1608Metric; LCSC C25804; not fitted
R21, R22, R23, R24, R25, R26: 470; R_0603_1608Metric; LCSC C23179

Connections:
+3V3: C1.1, J2.3, Q1.1 (G), Q2.1 (G), Q3.1 (G), Q4.1 (G), Q5.1 (G), Q6.1 (G), Q7.1 (G), R1.1, R2.1, R3.1, R4.1, R5.1, R6.1, R7.1, R21.1, R22.1, R23.1, R24.1, R25.1, R26.1
+12V: C2.1, C3.1, J1.2, J2.1, R11.1, R12.1, R13.1, R14.1, R15.1, R16.1, R17.1
/GP3: D1.1 (K), J2.5, Q1.2 (S), R1.2
/GP4: D2.1 (K), J2.6, Q2.2 (S), R2.2
/GP5: D3.1 (K), J2.7, Q3.2 (S), R3.2
/GP6: D4.1 (K), J2.8, Q4.2 (S), R4.2
/GP7: D5.1 (K), J2.9, Q5.2 (S), R5.2
/GP8: D6.1 (K), J2.10, Q6.2 (S), R6.2
/GP9: J2.11, Q7.2 (S), R7.2
/INHIBIT: J1.6, Q7.3 (D), R17.2
/LINE1: J1.7, Q1.3 (D), R11.2
/LINE2: J1.8, Q2.3 (D), R12.2
/LINE3: J1.9, Q3.3 (D), R13.2
/LINE4: J1.10, Q4.3 (D), R14.2
/LINE5: J1.3, Q5.3 (D), R15.2
/LINE6: J1.4, Q6.3 (D), R16.2
GND: C1.2, C2.2, C3.2, J1.1, J2.2, J2.4, J2.12
unnamed: D1.2 (A), R21.2
unnamed: D2.2 (A), R22.2
unnamed: D3.2 (A), R23.2
unnamed: D4.2 (A), R24.2
unnamed: D5.2 (A), R25.2
unnamed: D6.2 (A), R26.2

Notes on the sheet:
Переходник NRI G-13 <-> RP2350-Plus, 3.3 В
Двунаправленные BSS138: по одной и той же линии и читаем импульс монеты,
и блокируем канал, удерживая её в нуле.
Питание — всё с гребёнки:
3.3 В от платы, 12 В от внешнего источника
линия 1
линия 2
линия 3
линия 4
линия 5
линия 6
блокировка
Светодиод горит, пока линия притянута к нулю — то есть идёт импульс монеты.
R11…R16 ставить, только если приёмник не подтягивает линии сам: сначала измерьте.
R17 обязателен — без него на входе полной блокировки не наберётся 3,5 В.

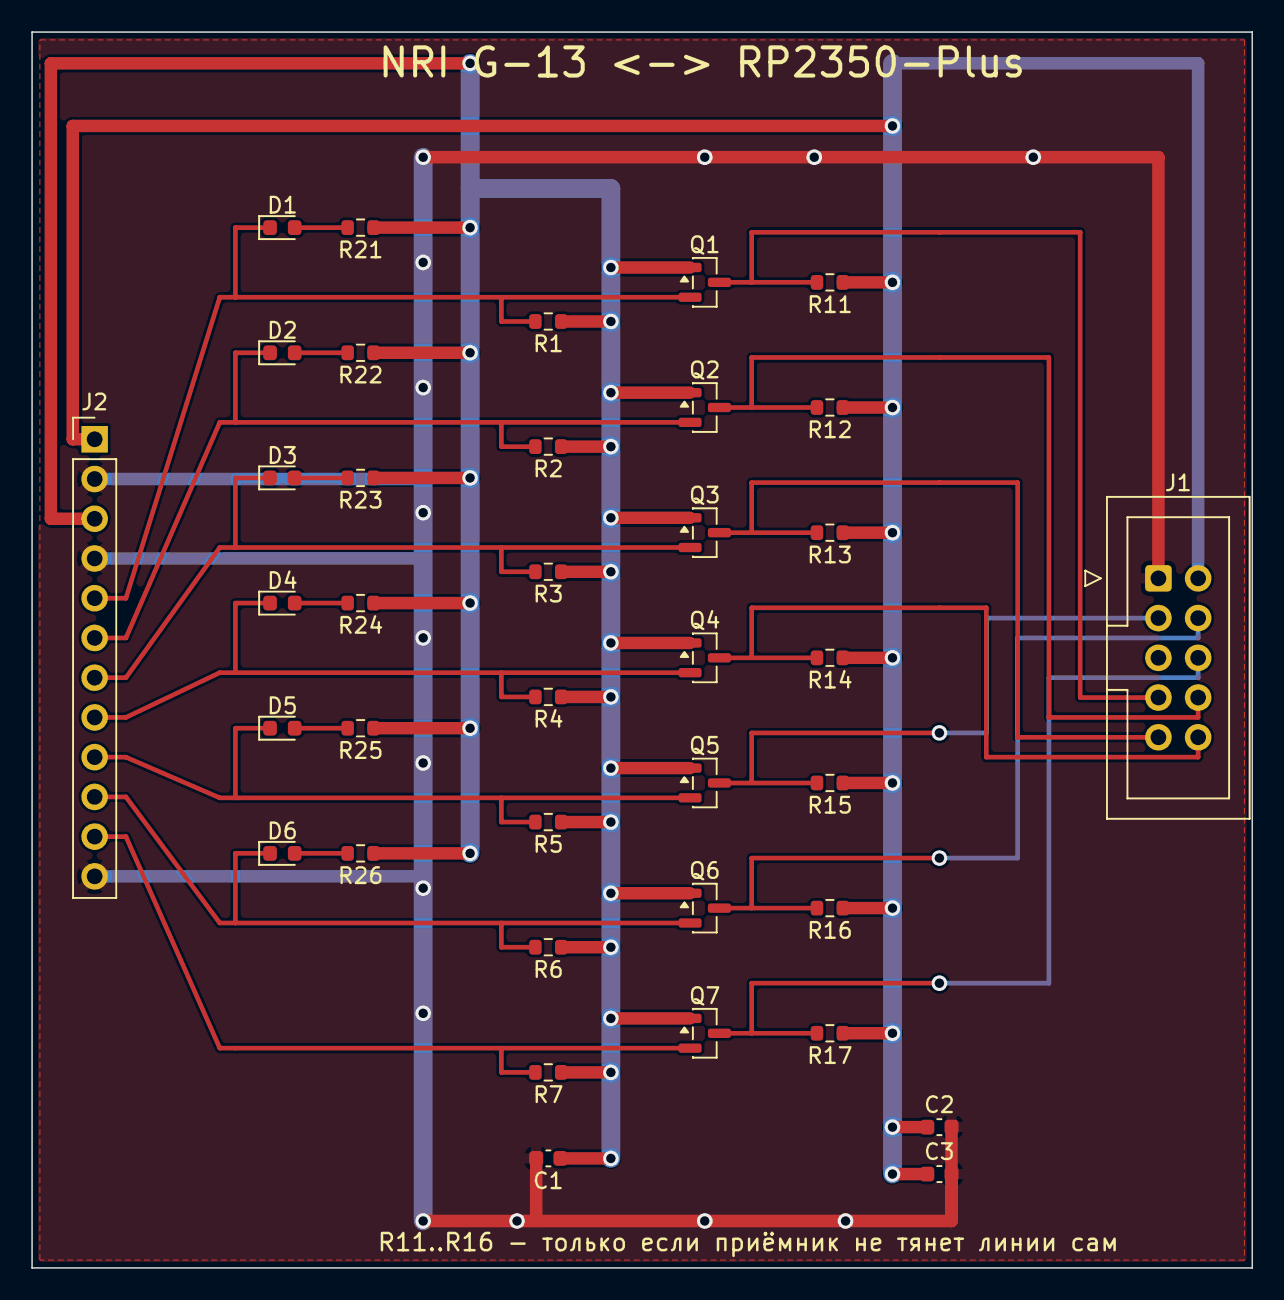
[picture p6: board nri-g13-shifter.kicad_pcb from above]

Board: 2 copper layers, 78.0 x 79.0 mm, 38 parts (0 on the bottom side), 23 nets.

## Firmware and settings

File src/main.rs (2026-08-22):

//! RP2350-Plus (Waveshare) + SIM800L: выход в интернет через PPP.
//!
//! Схема работы:
//!
//! ```text
//!   ┌───────── командный режим ─────────┐   ┌──── data-режим ────┐
//!   BufferedUart ──► atat::Ingress ──► ResponseSlot/UrcChannel
//!        ▲                                  BufferedUart ──► embassy-net-ppp
//!        └── atat::Client (AT+...)                              │
//!                                                        embassy-net (TCP/UDP/DNS)
//! ```
//!
//! Ключевая деталь: UART отдаётся то `atat`, то PPP — не одновременно.
//! Пока идёт настройка модема, задача ingress живёт внутри `select!` и
//! автоматически снимается, как только `bring_up` вернул `CONNECT`.
//! После этого тот же UART целиком уходит в `embassy_net_ppp::Runner::run`.

#![no_std]
#![no_main]

// Объявлен первым: `#![macro_use]` внутри fmt.rs делает info!/warn!/unwrap!
// видимыми во всех модулях ниже.
mod fmt;

mod app;
mod battery;
mod clock;
mod cmux;
mod cmux_transport;
mod coin;
mod coin_io;
mod config;
mod display;
mod fuel;
mod health;
mod io_compat;
mod led;
mod lipo;
mod modem;
mod mqtt;
mod sim800l;
#[cfg(feature = "log-usb")]
mod usb_logger;
mod watchdog;

use atat::asynch::{AtatClient, Client};
use atat::{AtatIngress, DefaultDigester, Ingress, ResponseSlot, UrcChannel, UrcSubscription};
use embassy_executor::Spawner;
use embassy_futures::select::{Either, Either3, select, select3};
use embassy_net::{Config as NetConfig, ConfigV4, Ipv4Cidr, StackResources, StaticConfigV4};
use embassy_embedded_hal::shared_bus::asynch::i2c::I2cDevice;
use embassy_rp::adc::{
    Adc, Channel as AdcChannel, Config as AdcConfig, InterruptHandler as AdcInterruptHandler,
};
use embassy_rp::bind_interrupts;
use embassy_rp::clocks::RoscRng;
use embassy_rp::gpio::{Flex, Input, Level, Output, Pull};
use embassy_rp::i2c::{Config as I2cConfig, I2c, InterruptHandler as I2cInterruptHandler};
use embassy_rp::peripherals::{I2C0, UART0};
use embassy_rp::uart::{BufferedInterruptHandler, BufferedUart, Config as UartConfig};
use embassy_rp::watchdog::{ResetReason as WatchdogReset, Watchdog as HwWatchdog};
use embassy_sync::blocking_mutex::raw::CriticalSectionRawMutex;
use embassy_sync::mutex::Mutex;
use embassy_sync::pipe::{DynamicReader, DynamicWriter, Pipe};
use embassy_time::{Duration, Instant, Timer};
use static_cell::StaticCell;

#[cfg(feature = "log-rtt")]
use defmt_rtt as _;
use panic_probe as _;

use crate::io_compat::Compat;
use crate::modem::Urc;

// --- Размеры буферов -------------------------------------------------------

/// Максимальный размер одного ответа AT.
///
/// 1 КиБ, а не 512 Б, из-за `AT+COPS=?`: список видимых сетей легко
/// перерастает полкилобайта, а переполнение ingress-буфера привело бы к
/// потере всего ответа.
const INGRESS_BUF_SIZE: usize = 1024;
/// Глубина очереди URC.
const URC_CAPACITY: usize = 8;
/// Сколько задач могут читать URC: логирование, детектор перезагрузок и
/// приём SMS.
const URC_SUBSCRIBERS: usize = 3;
/// Буфер сериализации исходящей AT-команды.
const CMD_BUF_SIZE: usize = 256;

/// TX-буфер UART. PPP шлёт кадры до ~1500 байт.
const UART_TX_BUF_SIZE: usize = 1024;
/// RX-буфер UART. Без аппаратного flow control это единственная защита от
/// переполнения на 115200 бод — меньше 2 КиБ ставить не стоит.
const UART_RX_BUF_SIZE: usize = 2048;

// --- Глобальное состояние atat --------------------------------------------

static RES_SLOT: ResponseSlot<INGRESS_BUF_SIZE> = ResponseSlot::new();
static URC_CHANNEL: UrcChannel<Urc, URC_CAPACITY, URC_SUBSCRIBERS> = UrcChannel::new();

/// Подписка на URC для тех, кто читает их адресно, а не ради лога.
///
/// Таких две — подъём модема и приём SMS, — но живут они по очереди, в разных
/// фазах. Вместе с постоянной подпиской `urc_task` отсюда и берётся
/// [`URC_SUBSCRIBERS`].
///
/// **Подписку нельзя держать дольше, чем её читают**: сообщение лежит в
/// очереди, пока его не забрали все подписчики, поэтому молчащий подписчик
/// через [`URC_CAPACITY`] сообщений запирает публикацию, а с ней и весь разбор
/// AT-канала. См. [`bring_up_subscription`].
pub type UrcSub = UrcSubscription<'static, Urc, URC_CAPACITY, URC_SUBSCRIBERS>;

/// Разборщик ответов модема со всеми размерами буферов, зафиксированными выше.
type ModemIngress =
    Ingress<'static, DefaultDigester<Urc>, Urc, INGRESS_BUF_SIZE, URC_CAPACITY, URC_SUBSCRIBERS>;

/// Размер приёмного буфера декодера CMUX: кадр PPP плюс запас.
const CMUX_DECODE_BUF: usize = 1600;
/// Труба AT-канала.
const CMUX_AT_PIPE: usize = 512;
/// Труба PPP-канала — должна вмещать хотя бы кадр PPP целиком.
const CMUX_PPP_PIPE: usize = 2048;

/// Сколько перезагрузок модуля подряд считать признаком проблем с питанием.
const RESET_STREAK_HINT: u32 = 3;

/// Скретч-регистр сторожевого таймера под признак тёплого перезапуска.
///
/// Переживает перезагрузку чипа и обнуляется при потере питания — именно то
/// различие, которое нужно, чтобы решить, трогать ли PWRKEY.
const WARM_BOOT_SLOT: usize = 0;
/// Произвольное значение; важно лишь, чтобы случайный мусор его не повторил.
const WARM_BOOT_MAGIC: u32 = 0x5350_5057;

/// После скольких подъёмов подряд **без единого ответа** дёрнуть PWRKEY.
///
/// Подстраховка к пропуску импульса на тёплом старте: если модуль всё-таки
/// оказался выключен, через несколько неудач мы его включим. Три попытки —
/// это около полуминуты, быстрее смысла нет.
///
/// Считается только молчание — см. [`revive_modem_if_stuck`].
const PWRKEY_AFTER_FAILURES: u32 = 3;

bind_interrupts!(struct Irqs {
    UART0_IRQ => BufferedInterruptHandler<UART0>;
    ADC_IRQ_FIFO => AdcInterruptHandler;
    I2C0_IRQ => I2cInterruptHandler<I2C0>;
});

/// Фоновая задача сетевого стека `embassy-net`.
#[embassy_executor::task]
async fn net_task(mut runner: embassy_net::Runner<'static, embassy_net_ppp::Device<'static>>) -> ! {
    runner.run().await
}

/// Логирование незапрошенных сообщений модема.
#[embassy_executor::task]
async fn urc_task(mut sub: UrcSubscription<'static, Urc, URC_CAPACITY, URC_SUBSCRIBERS>) -> ! {
    loop {
        let urc = sub.next_message_pure().await;
        info!("URC: {:?}", urc);
    }
}

/// Периодический замер питания.
///
/// GP29 = VSYS/3, GP24 = сенсор VBUS, GP23 = MODE/SYNC у MP28164 —
/// подробности и ограничения см. в `battery.rs`.
#[embassy_executor::task]
async fn battery_task(mut monitor: battery::PowerMonitor<'static>) -> ! {
    loop {
        match monitor.read().await {
            Ok(r) => match (r.vbat_mv, r.percent) {
                (Some(mv), Some(pct)) => info!(
                    "PWR: {:?}, батарея {} мВ ({} %), VSYS {} мВ",
                    r.source, mv, pct, r.vsys_mv
                ),
                _ => info!(
                    "PWR: {:?}, VSYS {} мВ (батарея не измеряется)",
                    r.source, r.vsys_mv
                ),
            },
            Err(e) => warn!("PWR: ошибка АЦП: {:?}", e),
        }
        Timer::after(Duration::from_secs(60)).await;
    }
}

#[embassy_executor::main]
async fn main(spawner: Spawner) {
    let p = embassy_rp::init(Default::default());

    // USB-логгер поднимаем первым делом, чтобы поймать как можно больше старта.
    // Хост всё равно enumerate'ит порт ~1 с, поэтому самые первые строки
    // осядут в буфере логгера и уйдут в терминал позже.
    #[cfg(feature = "log-usb")]
    spawner.spawn(unwrap!(usb_logger::logger_task(usb_logger::driver(p.USB))));

    info!("RP2350-Plus + SIM800L: старт");

    // --- Сторожевой таймер -------------------------------------------------
    // Заводим до всего остального: дальше идут ожидания на секунды, и к ним
    // задача кормления должна быть уже запущена.
    let mut hw_watchdog = HwWatchdog::new(p.WATCHDOG);
    // Печатаем строкой, а не через `{:?}`: `ResetReason` реализует `Debug`, но
    // не `defmt::Format`, и сборка с RTT на нём не собралась бы.
    if let Some(reason) = hw_watchdog.reset_reason() {
        warn!(
            "WDT: прошлый запуск оборвала перезагрузка ({})",
            match reason {
                WatchdogReset::TimedOut => "не покормили",
                WatchdogReset::Forced => "принудительная",
            }
        );
    }
    // Скретч переживает перезагрузку, но не потерю питания — ровно то, что
    // нужно, чтобы отличить тёплый перезапуск от холодного старта.
    let warm_boot = hw_watchdog.get_scratch(WARM_BOOT_SLOT) == WARM_BOOT_MAGIC;
    hw_watchdog.set_scratch(WARM_BOOT_SLOT, WARM_BOOT_MAGIC);
    spawner.spawn(unwrap!(watchdog::watchdog_task(hw_watchdog)));

    // GP2 -> PWRKEY модуля. Если PWRKEY не разведён (модуль стартует сам),
    // пин просто останется неиспользуемым выходом.
    let mut pwrkey = Output::new(p.PIN_2, Level::High);

    // --- Мониторинг питания -----------------------------------------------
    // PIN_23/24/29 разведены на плате и на гребёнку не выходят.
    let monitor = battery::PowerMonitor::new(
        Adc::new(p.ADC, Irqs, AdcConfig::default()),
        AdcChannel::new_pin(p.PIN_29, Pull::None),
        Input::new(p.PIN_24, Pull::None),
        Output::new(p.PIN_23, Level::Low),
    );
    spawner.spawn(unwrap!(battery_task(monitor)));

    // --- UART на GP0 (TX) / GP1 (RX) --------------------------------------
    static UART_TX_BUF: StaticCell<[u8; UART_TX_BUF_SIZE]> = StaticCell::new();
    static UART_RX_BUF: StaticCell<[u8; UART_RX_BUF_SIZE]> = StaticCell::new();

    let mut uart_config = UartConfig::default();
    uart_config.baudrate = config::UART_BAUDRATE;

    let uart = BufferedUart::new(
        p.UART0,
        p.PIN_0,
        p.PIN_1,
        Irqs,
        UART_TX_BUF.init([0; UART_TX_BUF_SIZE]),
        UART_RX_BUF.init([0; UART_RX_BUF_SIZE]),
        uart_config,
    );

    // --- PPP-драйвер как embassy-net Device -------------------------------
    static PPP_STATE: StaticCell<embassy_net_ppp::State<4, 4>> = StaticCell::new();
    let (device, ppp_runner) = embassy_net_ppp::new(PPP_STATE.init(embassy_net_ppp::State::new()));

    // --- Сетевой стек ------------------------------------------------------
    // IP-конфигурацию не задаём: её принесёт IPCP при подъёме PPP.
    let seed = RoscRng.next_u64();
    static RESOURCES: StaticCell<StackResources<4>> = StaticCell::new();
    let (stack, net_runner) = embassy_net::new(
        device,
        NetConfig::default(),
        RESOURCES.init(StackResources::new()),
        seed,
    );

    spawner.spawn(unwrap!(net_task(net_runner)));
    spawner.spawn(unwrap!(urc_task(unwrap!(URC_CHANNEL.subscribe().ok()))));
    spawner.spawn(unwrap!(app::demo_task(stack)));
    // Монетоприёмник: шесть линий на GP3..GP8. Именно `Flex`, а не `Input`:
    // по этим же линиям канал блокируется удержанием нуля — см. `coin_io`.
    // Маску задаём до запуска задач, чтобы линии без номинала не успели
    // проглотить монету.
    coin_io::init();
    let coin_lines = [
        Flex::new(p.PIN_3),
        Flex::new(p.PIN_4),
        Flex::new(p.PIN_5),
        Flex::new(p.PIN_6),
        Flex::new(p.PIN_7),
        Flex::new(p.PIN_8),
    ];
    spawner.spawn(unwrap!(coin_io::coin_task(coin_lines)));
    // Полная блокировка — контакт 6 приёмника. Вывод создаётся внутри задачи:
    // полярность зависит от буферного каскада, и знать о ней должен один файл.
    spawner.spawn(unwrap!(coin_io::total_block_task(p.PIN_9)));

    // Шина I2C0 на GP16 (SDA) / GP17 (SCL): экран SSD1306 и топливомер
    // MAX17048 висят на ней вдвоём, поэтому она за мьютексом.
    //
    // Мьютекс асинхронный, хотя крейт топливомера блокирующий: `embassy_rp`
    // реализует оба трейта доступа к шине сразу, так что экран ходит через
    // асинхронную обёртку, а топливомер берёт замок и обращается напрямую.
    static I2C_BUS: StaticCell<fuel::I2cBus> = StaticCell::new();
    let i2c_bus = I2C_BUS.init(Mutex::new(I2c::new_async(
        p.I2C0,
        p.PIN_17,
        p.PIN_16,
        Irqs,
        I2cConfig::default(),
    )));

    spawner.spawn(unwrap!(display::display_task(I2cDevice::new(i2c_bus))));
    spawner.spawn(unwrap!(fuel::fuel_task(i2c_bus)));

    // Зелёный светодиод на GP25 — через R19 470R на землю, активен высоким.
    spawner.spawn(unwrap!(led::led_task(Output::new(p.PIN_25, Level::Low))));
    spawner.spawn(unwrap!(mqtt::mqtt_task(stack)));

    // --- atat: ingress + буфер команд -------------------------------------
    static INGRESS_BUF: StaticCell<[u8; INGRESS_BUF_SIZE]> = StaticCell::new();
    static CMD_BUF: StaticCell<[u8; CMD_BUF_SIZE]> = StaticCell::new();

    // Две надстройки над штатным дайджестером, обе — под особенности SIM800L:
    //
    // * `SHUT OK` в ответ на AT+CIPSHUT успехом не считается;
    // * приглашение `> ` при отправке SMS не заканчивается переводом строки и
    //   на ответ не похоже вовсе.
    let ingress = Ingress::new(
        DefaultDigester::<Urc>::new()
            .with_custom_success(modem::parse_shut_ok)
            .with_custom_prompt(modem::parse_sms_prompt),
        INGRESS_BUF.init([0; INGRESS_BUF_SIZE]),
        &RES_SLOT,
        &URC_CHANNEL,
    );
    let cmd_buf = CMD_BUF.init([0; CMD_BUF_SIZE]);

    let ppp_config = embassy_net_ppp::Config {
        username: config::PPP_USERNAME,
        password: config::PPP_PASSWORD,
    };

    // Импульс PWRKEY **переключает** питание модуля, а не включает его. После
    // перезагрузки по сторожевому таймеру модуль остался работать, и импульс
    // его бы выключил — поэтому на тёплом старте пропускаем.
    //
    // Ошибиться здесь не страшно: если модуль всё-таки окажется выключен, его
    // включит фаза подъёма, не добившись ответа, — см. `PWRKEY_AFTER_FAILURES`.
    if warm_boot {
        info!("SIM800L: тёплый перезапуск, PWRKEY не трогаем");
    } else {
        sim800l::power_on(&mut pwrkey).await;
    }

    if config::USE_CMUX {
        run_multiplexed(
            uart,
            ppp_runner,
            stack,
            ingress,
            cmd_buf,
            &mut pwrkey,
            ppp_config,
        )
        .await
    } else {
        run_plain(
            uart,
            ppp_runner,
            stack,
            ingress,
            cmd_buf,
            &mut pwrkey,
            ppp_config,
        )
        .await
    }
}

/// Подписка на URC для фазы подъёма модема.
///
/// Живёт **только** на время подъёма и умирает перед тем, как канал заработает.
/// Так и задумано: очередь URC хранит сообщение, пока его не забрали все
/// подписчики, поэтому подписка, которую никто не читает, через
/// [`URC_CAPACITY`] сообщений намертво запирает публикацию. А публикует
/// `atat::Ingress`, и заперев её, мы останавливаем разбор всего AT-канала.
///
/// Ровно поэтому подписку нельзя завести один раз на всю программу — на
/// поднятом канале её никто не опрашивает.
fn bring_up_subscription() -> UrcSub {
    unwrap!(URC_CHANNEL.subscribe().ok())
}

/// Дёрнуть PWRKEY, если подъём не удаётся подряд слишком много раз.
///
/// Нужно из-за того, что импульс PWRKEY **переключает** питание модуля. После
/// перезагрузки по сторожевому таймеру мы его не трогаем — модуль работает, и
/// импульс бы его выключил. Но если предположение неверно и модуль всё-таки
/// мёртв, ждать вечно нельзя: несколько неудач подряд — достаточный повод.
///
/// Счётчик сбрасывается, чтобы дёргать не чаще, чем раз в
/// [`PWRKEY_AFTER_FAILURES`] попыток: включение модуля занимает секунды, и
/// повторять его на каждой итерации значило бы не давать ему стартовать.
///
/// # Считается только молчание
///
/// Годится ровно одна ошибка — [`NoResponse`](sim800l::BringUpError::NoResponse).
/// Все остальные означают, что модуль **отвечает**, и импульс его выключит.
/// Особенно `ModemReset`: он приходит при провале питания, когда модуль
/// перезагружается сам. Считать его поводом дёрнуть PWRKEY — значит гасить
/// живой модем посреди и без того тяжёлого цикла.
async fn revive_modem_if_stuck(
    pwrkey: &mut Output<'static>,
    silent_streak: &mut u32,
    error: &sim800l::BringUpError,
) {
    if !matches!(error, sim800l::BringUpError::NoResponse) {
        *silent_streak = 0;
        return;
    }

    *silent_streak += 1;
    if *silent_streak < PWRKEY_AFTER_FAILURES {
        return;
    }

    warn!(
        "SIM800L: молчит {} попыток подряд, пробую импульс PWRKEY",
        silent_streak
    );
    *silent_streak = 0;
    sim800l::power_on(pwrkey).await;
}

/// Применить IPv4-конфигурацию, полученную по IPCP.
fn apply_ipv4(stack: embassy_net::Stack<'static>, ipv4: embassy_net_ppp::Ipv4Status) {
    let Some(address) = ipv4.address else {
        warn!("PPP: пир не выдал IPv4-адрес");
        return;
    };

    let mut dns_servers = heapless::Vec::new();
    for server in ipv4.dns_servers.iter().flatten() {
        let _ = dns_servers.push(*server);
    }

    info!("PPP: адрес {:?}, пир {:?}", address, ipv4.peer_address);

    // Маска /0 + отсутствие шлюза — стандартная конфигурация для
    // point-to-point линка: весь трафик уходит в PPP-интерфейс.
    stack.set_config_v4(ConfigV4::Static(StaticConfigV4 {
        address: Ipv4Cidr::new(address, 0),
        gateway: None,
        dns_servers,
    }));
}

/// Проверенный путь: UART принадлежит то `atat`, то PPP.
///
/// Пока канал поднят, модем недоступен для команд — ради снятия этого
/// ограничения и делается [`run_multiplexed`].
async fn run_plain(
    mut uart: BufferedUart,
    mut ppp_runner: embassy_net_ppp::Runner<'static>,
    stack: embassy_net::Stack<'static>,
    mut ingress: ModemIngress,
    cmd_buf: &'static mut [u8; CMD_BUF_SIZE],
    pwrkey: &mut Output<'static>,
    ppp_config: embassy_net_ppp::Config<'static>,
) -> ! {
    // Сколько раз подряд модуль перезагрузился посреди инициализации.
    let mut reset_streak = 0u32;
    // Сколько раз подряд модуль вообще не отозвался на `AT`.
    let mut silent_streak = 0u32;

    loop {
        // ---------- фаза 1: командный режим (atat владеет UART) ----------
        ingress.clear();

        let bring_up = {
            // Подписка живёт ровно этот блок — см. `bring_up_subscription`.
            let mut bring_up_urc = bring_up_subscription();
            let (uart_tx, uart_rx) = uart.split_ref();
            // Compat(..) переносит UART из embedded-io-async 0.7 в 0.6 — см. io_compat.
            let mut client = Client::new(
                Compat(uart_tx),
                &RES_SLOT,
                &mut cmd_buf[..],
                atat::Config::new(),
            );

            // read_from() никогда не возвращается; `;` приводит `!` к `()`.
            let ingress_fut = async {
                ingress.read_from(Compat(uart_rx)).await;
            };
            let setup_fut = sim800l::bring_up(&mut client, config::APN, &mut bring_up_urc);

            match select(ingress_fut, setup_fut).await {
                Either::First(()) => unreachable!(),
                Either::Second(result) => result,
            }
        };

        if let Err(e) = bring_up {
            report_bring_up_error(&e, &mut reset_streak);
            revive_modem_if_stuck(pwrkey, &mut silent_streak, &e).await;
            // Вернуть модем в вменяемое состояние и попробовать снова.
            sim800l::escape_data_mode(&mut uart).await;
            Timer::after(Duration::from_secs(config::RECONNECT_DELAY_SECS)).await;
            continue;
        }

        reset_streak = 0;
        silent_streak = 0;

        // ---------- фаза 2: data-режим (PPP владеет UART) ----------
        let result = ppp_runner
            .run(&mut uart, ppp_config.clone(), |ipv4| {
                apply_ipv4(stack, ipv4)
            })
            .await;

        // Ok-вариант — Infallible: run() возвращается только с ошибкой.
        match result {
            Err(e) => warn!(
                "PPP-сессия завершена: {:?}, всего обрывов {}",
                e,
                health::link_dropped()
            ),
        }

        // Снимаем протухшую конфигурацию, чтобы wait_config_up() снова блокировал.
        stack.set_config_v4(ConfigV4::None);

        // ---------- фаза 3: возврат в командный режим ----------
        sim800l::escape_data_mode(&mut uart).await;
        Timer::after(Duration::from_secs(config::RECONNECT_DELAY_SECS)).await;
    }
}

fn report_bring_up_error(e: &sim800l::BringUpError, reset_streak: &mut u32) {
    if matches!(e, sim800l::BringUpError::ModemReset) {
        *reset_streak += 1;
        warn!(
            "Модуль перезагрузился во время инициализации (подряд: {})",
            reset_streak
        );
        if *reset_streak >= RESET_STREAK_HINT {
            error!(
                "SIM800L перезагружается циклически. Регистрация идёт на полной \
                 мощности передатчика (до 2 А импульсами) — проверьте питание: \
                 электролит 1000 мкФ прямо на VCC/GND модуля, отдельные толстые \
                 провода от аккумулятора мимо макетки, заряд батареи."
            );
        }
    } else {
        *reset_streak = 0;
        error!("Инициализация модема не удалась: {:?}", e);
    }
}
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

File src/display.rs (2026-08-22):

//! Графический экран SSD1306 по I2C: время из сети и уровень сигнала.
//!
//! ```text
//!   RP2350
//!   GP16 ── SDA ──┐
//!   GP17 ── SCL ──┤ SSD1306 128x64, адрес 0x3C или 0x3D
//!   3V3  ── VCC ──┤
//!   GND  ── GND ──┘
//! ```
//!
//! Что на экране:
//!
//! ```text
//! ┌──────────────────────────────┐
//! │ 12:34        85%    ▁▃▅▇█    │  время, заряд батареи, шкала сигнала
//! │ 2026-08-16                   │
//! │ Кредит 1.50                  │  накоплено монетоприёмником
//! │ -73dBm MQTT + 0/2            │  обрывы: MQTT / канала
//! └──────────────────────────────┘
//! ```
//!
//! Два счётчика в нижней строке — не украшение. Мгновенное состояние скрывает
//! главное: связь, разваливающаяся каждые полминуты, выглядит здесь ровно как
//! исправная, если посмотреть в удачную секунду. Считаются они от включения и
//! обнуляются перезагрузкой, в том числе по сторожевому таймеру.
//!
//! Время приходит от сотовой сети — см. [`crate::clock`]. Пока сеть его не
//! прислала, вместо часов выводится «--:--»: показывать заводскую дату модема
//! (2004 год) значило бы врать правдоподобно выглядящими цифрами.
//!
//! Заряд приходит от топливомера MAX17048 — см. [`crate::fuel`]. Шина у них
//! общая, поэтому она за мьютексом. Если топливомера нет, вместо процентов
//! стоит прочерк: пустое место читалось бы как «показа заряда тут не
//! предусмотрено».
//!
//! Экран необязателен. Если по шине никто не отозвался, задача сообщает об
//! этом в лог и засыпает: связь и телеметрия от наличия дисплея не зависят.

use embassy_embedded_hal::shared_bus::asynch::i2c::I2cDevice;
use embassy_rp::i2c::{Async, I2c};
use embassy_rp::peripherals::I2C0;
use embassy_sync::blocking_mutex::raw::CriticalSectionRawMutex;
use embassy_time::{Duration, Timer};
use embedded_graphics::mono_font::MonoTextStyle;
// Кириллический набор: шрифты `ascii` вместо русских букв рисуют заглушку.
use embedded_graphics::mono_font::iso_8859_5::{FONT_6X10, FONT_10X20};
use embedded_graphics::pixelcolor::BinaryColor;
use embedded_graphics::prelude::*;
use embedded_graphics::primitives::{PrimitiveStyle, Rectangle};
use embedded_graphics::text::Text;
use ssd1306::mode::BufferedGraphicsModeAsync;
use ssd1306::prelude::*;
use ssd1306::{I2CDisplayInterface, Ssd1306Async};

use crate::clock;
use crate::coin;
use crate::coin_io;
use crate::fuel;
use crate::health;
use crate::mqtt;

/// Адреса, на которых встречаются эти модули. `0x3C` — заводской, `0x3D`
/// получается перепайкой перемычки на плате.
const CANDIDATE_ADDRESSES: [u8; 2] = [0x3C, 0x3D];

/// Как часто перерисовывать. Раз в секунду достаточно для часов и не грузит
/// шину.
const REFRESH: Duration = Duration::from_secs(1);

// Разметка шкалы сигнала: пять столбиков в правом верхнем углу.
const BAR_COUNT: i32 = 5;
const BAR_WIDTH: i32 = 5;
const BAR_GAP: i32 = 2;
const BAR_BASELINE: i32 = 20;
const BAR_RIGHT: i32 = 126;

/// Где начинается заряд батареи: правее часов, левее шкалы сигнала.
const BATTERY_X: i32 = 58;

/// Шина у экрана общая с топливомером, отсюда обёртка вместо самой шины.
type SharedI2c = I2cDevice<'static, CriticalSectionRawMutex, I2c<'static, I2C0, Async>>;

type Display = Ssd1306Async<
    I2CInterface<SharedI2c>,
    DisplaySize128x64,
    BufferedGraphicsModeAsync<DisplaySize128x64>,
>;

/// Найти экран на шине.
///
/// Пробуем оба адреса: заводской и переставленный перемычкой. Возвращаем
/// `None`, если не отозвался никто.
async fn probe(mut i2c: SharedI2c) -> Option<Display> {
    let mut found = None;
    for address in CANDIDATE_ADDRESSES {
        // Байт 0x00 — префикс потока команд; сам по себе он безвреден и годится
        // как проверка присутствия. Обращаемся через трейт: шина теперь за
        // общей обёрткой, и собственных методов embassy-rp у неё нет.
        if embedded_hal_async::i2c::I2c::write(&mut i2c, address, &[0x00u8])
            .await
            .is_ok()
        {
            info!("OLED: найден по адресу 0x{:02x}", address);
            found = Some(address);
            break;
        }
    }

    let address = found?;
    let interface = I2CDisplayInterface::new_custom_address(i2c, address);
    let mut display = Ssd1306Async::new(interface, DisplaySize128x64, DisplayRotation::Rotate0)
        .into_buffered_graphics_mode();

    if display.init().await.is_err() {
        warn!("OLED: инициализация не удалась");
        return None;
    }
    Some(display)
}

/// Нарисовать шкалу сигнала: заполненные деления сплошные, остальные контуром.
///
/// Контур вместо пустоты — чтобы было видно, сколько делений всего, и слабый
/// сигнал не выглядел как отсутствие экрана.
fn draw_signal(display: &mut Display, bars: u8) {
    let filled = PrimitiveStyle::with_fill(BinaryColor::On);
    let outline = PrimitiveStyle::with_stroke(BinaryColor::On, 1);
    let total_width = BAR_COUNT * BAR_WIDTH + (BAR_COUNT - 1) * BAR_GAP;
    let left = BAR_RIGHT - total_width;

    for index in 0..BAR_COUNT {
        let height = 4 + index * 3;
        let rect = Rectangle::new(
            Point::new(left + index * (BAR_WIDTH + BAR_GAP), BAR_BASELINE - height),
            Size::new(BAR_WIDTH as u32, height as u32),
        );
        let style = if index < bars as i32 { filled } else { outline };
        let _ = rect.into_styled(style).draw(display);
    }
}
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

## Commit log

2026-08-13 RP2350-Plus + SIM800L: выход в интернет через PPP
    Embassy-приложение для Waveshare RP2350-Plus: настройка GSM-модуля SIM800L
    через atat, IP-канал через embassy-net-ppp, сокеты через embassy-net.
    Один UART обслуживает две фазы, но никогда одновременно: во время AT-настройки
    задача atat::Ingress живёт внутри select и снимается, как только модем ответил
    CONNECT, после чего UART целиком уходит в embassy_net_ppp::Runner::run. При
    развале PPP-сессии приложение шлёт ++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
2026-08-13 Измерение питания: VSYS/VBAT, источник, заряд Li-Po
    По официальной схеме RP2350-Plus: GP29/ADC3 = VSYS/3 (делитель R1 200K /
    R7 100K, C7 100nF), GP24 — сенсор VBUS, GP23 — MODE/SYNC у MP28164. На время
    замера преобразователь переводится в режим постоянной ШИМ, иначе пульсации
    VSYS дают разброс в десятки милливольт.
    Ключ Q1 (SI2306) между делителем и GP29 управления не требует: затвор жёстко
    на 3V3, при снятом 3V3 ключ отвязывает ногу МК от VSYS.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
2026-08-14 AT&W и расширенный детектор перезагрузок модуля
    ATE0 и AT+IPR жили только до следующего сброса: после провала питания SIM800L
    возвращается к автоопределению скорости и отвечает на чужой, из-за чего его
    RDY приходил битым и оседал в Framing error. Теперь настройки закрепляются
    в профиле модуля через AT&W.
    Команда вызывается один раз за загрузку контроллера, а не в каждом цикле
    переподключения: AT&W рас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
    [sim800l.rs]
2026-08-14 README: измеренный эффект конденсатора на VCC модуля
    Рекомендация про 1000 мкФ была общей, теперь под ней есть цифры с этого
    стенда: без конденсатора 14 сбросов питания за 172 с с периодом ~11 с, с ним
    ноль за 140 с. Показательна не столько статистика, сколько момент смерти —
    CSQ успевал вырасти с 0 до 20, и через 6 мс приходил Break error. Приём идёт
    на десятках миллиампер, регистрация требует передачи на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
2026-08-14 Дозвон падал с Parse: SIM800L отвечает на AT+CIPSHUT строкой SHUT OK
    Дайджестер atat считает успехом только OK и CONNECT. Строка "\r\nSHUT OK\r\n"
    не содержит "\r\nOK\r\n" как подстроку, поэтому не распознавалась вовсе:
    AT+CIPSHUT отваливался по таймауту в 65 секунд, а сами байты оставались в
    приёмном буфере. Дальше они приклеивались к ответу на дозвон, и ATD получал
    тело "SHUT OK" вместо пустого — отсюда Error::Parse и DialFailed.
    На живо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
    [main.rs]
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2026-08-15 MQTT: сменить брокер по умолчанию и логировать адрес
    На стенде каждая попытка подключения получала RST. Причина оказалась не в
    коде и не в GPRS: test.mosquitto.org был недоступен и из обычного интернета —
    «No route to host». Публичный брокер выбран дефолтом опрометчиво.
    Заменён на broker.hivemq.com, он отвечает.
    Разрешённый адрес теперь пишется в лог: без него отказ брокера неотличим от
    проблем с DNS или маршру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
2026-08-16 Монетоприёмник NRI G-13: приём монет и блокировка каналов по MQTT
    Шесть линий на GP3..GP8. Линии двунаправленные: по ним же приходит
    импульс о монете и задаётся блокировка канала удержанием нуля — отсюда
    Flex вместо Input. Единицу не выдаём никогда, с той стороны открытый
    коллектор.
    Логика (кредит, разбор команды блокировки) вынесена в coin.rs без
    зависимостей и проверяется на хосте; всё, что трога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
    [display.rs, main.rs]
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2026-08-18 Схема переходника NRI G-13 <-> RP2350-Plus на BSS138
    Семь двунаправленных преобразователей уровней: шесть линий монет и линия
    полной блокировки. По одной и той же линии приёмник выдаёт импульс о
    монете и принимает блокировку канала, а порог приёма у него 3.5 В — выше
    того, что выдаёт плата. Отсюда BSS138, как в схеме предыдущего поколения
    устройства.
    Схема генерируется скриптом. Семь каналов отлича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
    [nri-g13-shifter.kicad_sch]
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2026-08-18 Разводка платы переходника: два слоя, 96x92 мм
    Ортогональная схема разводки, и это не украшательство, а то, что
    позволило сгенерировать её скриптом: верх — сигналы горизонтальными
    строками по строке на канал, низ — питание вертикальными шинами поперёк
    всех строк. Пересечься они не могут по построению, а семь строк
    отличаются только координатой y.
    Две тонкости пришлось развести отде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
    [nri-g13-shifter.kicad_pcb]
2026-08-18 Плата компактнее на треть, 12 В переехало в гребёнку
    Клеммник убран, питание приёмника идёт через ту же гребёнку, что и
    сигналы: отдельный разъём означал бы второй кабель к устройству, которое
    и так стоит в тесном корпусе. Гребёнка стала двенадцатиконтактной, а
    сигнальные выводы по-прежнему идут подряд и в порядке строк платы —
    от этого веер разводки остаётся непересекающимся сам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
    [nri-g13-shifter.kicad_pcb, nri-g13-shifter.kicad_sch]
2026-08-18 Заливка землёй по обоим слоям, шины питания шире
    Обе заливки получились сплошными: сигналы идут наверху горизонтальными
    полосами, питание внизу вертикальными, и ни то, ни другое не режет плату
    поперёк.
    Дорожки земли под заливкой оставлены намеренно. Заливка на плотной плате
    может разорваться на куски, и надеяться, что все они окажутся связаны,
    нельзя, — а дорожка связывает гарант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
    [nri-g13-shifter.kicad_pcb]
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2026-08-18 Производственный комплект: гербера, сверловка, архив
    make_gerbers.sh собирает всё одной командой и кладёт готовый архив для
    загрузки на завод.
    --check-zones обязателен и стоит в скрипте: заливку заполняет KiCad, а не
    gen_pcb.py, и без него на производство уехала бы плата с пустыми зонами,
    то есть без земли.
    Отчёт по сверловке заодно проверяет замысел: 50 отверстий по 0.6 мм — это
    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
    [nri-g13-shifter-B_Cu.gbr, nri-g13-shifter-B_Mask.gbr, nri-g13-shifter-B_Paste.gbr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]
2026-08-18 Комплект для монтажа: перечень элементов и координаты установки
    make_gerbers.sh теперь кладёт в assembly/ ещё и bom.csv с cpl.csv — без
    них заказ на монтаж не примут.
    --exclude-dnp в обоих вызовах: R11..R16 ставить не нужно, и завод не
    должен узнавать об этом из примечания в письме.
    Колонку с артикулом склада намеренно не заполнял: неверный артикул — это
    не опечатка, а другая деталь на плате. Подбирать в катало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
    [bom.csv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]
2026-08-18 Артикулы JLCPCB и исправление номинала C3
    Артикулы проставлены в схеме, при компонентах, и оттуда попадают и в
    bom.csv, и в плату. Все сверены по каталогу, а не восстановлены по
    памяти: неверный код — это не опечатка, а другая деталь на плате.
    Подбор артикулов и вскрыл ошибку: C3 стоял на 10 мкФ, а в корпусе 0603
    такая ёмкость бывает только на 10 вольт. Сидит эта банка на шине 12 В,
    то есть номинал бы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
    [bom.csv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]
2026-08-18 Файлы для монтажа приведены к тому, что ставит станок
    --exclude-fp-th: выводные разъёмы на автоматический монтаж не идут, и
    оставлять их в файле — значит получить вопрос от завода вместо платы.
    Перечень приводится к тому же составу, что и координаты: строка без
    координат установки — тоже лишний вопрос.
    Осталось 30 деталей: 38 всего минус 6 неустанавливаемых минус два разъёма.
    В README добавле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
    [bom.csv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]
2026-08-18 Файлы монтажа в формате, который принимает JLCPCB
    Завод отвергал их с «File processing failed» без подробностей. Причин
    две, и обе от того, что KiCad и JLCPCB называют одно и то же по-разному.
    Обозначения KiCad сворачивает в диапазоны — D1-D6, R1-R7. Завод их не
    разбирает и ждёт перечисления поштучно: --ref-range-delimiter ''.
    Шапка координат у KiCad своя: Ref, Val, Package, PosX, PosY, Rot, Side.
    Ждут Designator, Mid X, Mid Y, Rotation, Layer. Переименование и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
    [bom.csv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]
2026-08-18 Светодиод красный, резистор 470 Ом: зелёный не зажёгся бы вовсе
    JLCPCB не сопоставил C72043 — снят с наличия. При проверке замены
    выяснилось худшее: у зелёного в корпусе 0603 прямое напряжение 3.3 В,
    ровно столько же, сколько на шине, от которой он питается. Через 1 кОм
    ток получался бы нулевой, и шесть индикаторов просто не горели бы.
    Красный C2286 (KT-0603R): 1.8…2.4 В, склад под четыре миллиона штук.
    Рез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
    [bom.csv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]
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2026-08-21 Счётчики обрывов связи, на экране рядом с состоянием MQTT
    Разница между «связь есть» и «связь есть прямо сейчас, а до этого
    пропадала двадцать раз» видна только по счётчику. Мгновенное состояние её
    скрывает: канал, разваливающийся каждые полминуты, выглядит на экране
    ровно как исправный, если посмотреть в удачную секунду. Вчерашние сутки
    это подтвердили дважды.
    Уровня два и считаю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
    [display.rs, main.rs]
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
